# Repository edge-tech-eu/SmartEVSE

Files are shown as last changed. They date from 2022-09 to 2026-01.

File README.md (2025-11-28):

# SmartEVSE

ModBusRegisters.pdf lists the ModBus-RTU/RS485 registers. The SmartEVSE operates by default at 9600 BAUD (8 bits, no parity, 1 stop bit). Be aware that a state change (e.g. pressing the button on the board) is needed before communication is possible with the SmartEVSE with default address 1.

Note that important registers are protected by "magic" (first write the magic code, input register 0x0202) and settings are only persistent after writing them to EEPROM (input register 0x000a)

Installation.png is an quick overview on how to install the SmartEVSE

SmartEVSE mounts can be found in the '3d' folder

Are you looking for the guidelines on building your own charge point? Then continue [here](DHZ-laadpaal.md) (that document is in Dutch).

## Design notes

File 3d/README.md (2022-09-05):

This folder contains 3D designs of brackets to mount the SmartEVSE

The files with extension stl or 3mf can be 3D printed directly

The files with extension f3d are Autodesk Fusion 360 design files

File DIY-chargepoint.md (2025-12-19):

# DIY charging station
Voor Nederlands zie [hier](DHZ-laadpaal.md)

Look, we've done all the prep work for you!
We'll now help you put everything together step by step.

Follow the steps in the overview below:
1. [The basic configuration](installation/module-kl.png) – the “dumb charging station”, i.e. without load balancing
2. With power control (load balancing). Then choose one of the options below:
   - Use an ESP device or a Pi pico connected to a DSMR 4 or 5 smart meter and connect it to the charging station via an RS485 cable (Modbus)
   - Use a Raspberry Pi mini-computer with a USB cable connected to a DSMR 4 or 5 smart meter and an RS485 interface. Use the EVCC package to control the charging station
   - Use the Edgetech WiFi module:
     1. Do you have a DSMR5 smart meter? Then you can connect the EVSE-SC-02 module directly to the smart meter
     2. Do you not have a smart meter or do you have an older type? Then the current must be measured with current clamps (CT) and you will need type EVSE-SC-01.

> [!IMPORTANT]
> This document is written for experienced hobbyists. In other words, people who know how to safely connect devices to a 3-phase power cable.
> People who know what earth leakage circuit breakers are and understand the basic principles of connecting large power consumers via the meter box.
> We always recommend that changes to the meter box be carried out by a certified electrician.
# 1. The Basic configuration

With the basic configuration, you create a charging point without power control. This means that the charging point does not take other power users in the house into account. This can potentially cause problems if the power demand is too high. Therefore, ensure that you only charge when there is sufficient capacity available. This is typically the case from 10 p.m. to 4 a.m. Take into account the possible presence of heat pumps, home batteries and electric boilers. The basic configuration consists of the following components:

- charging module
- DC earth leakage module with connection cable
- charging cable
- housing and cable glands
- mounting brackets

You can easily assemble this housing yourself. You also have the option of using the mounting brackets if the standard mounting of the charging module is not suitable for your situation.

## Connecting the LED

You can connect a 5VDC or 12VDC LED to the charging module.

[Click here](installation/adding%20LED%20to%20charger.pdf) for the connection diagram.

## Assembly steps

- Below is an overview of all connections

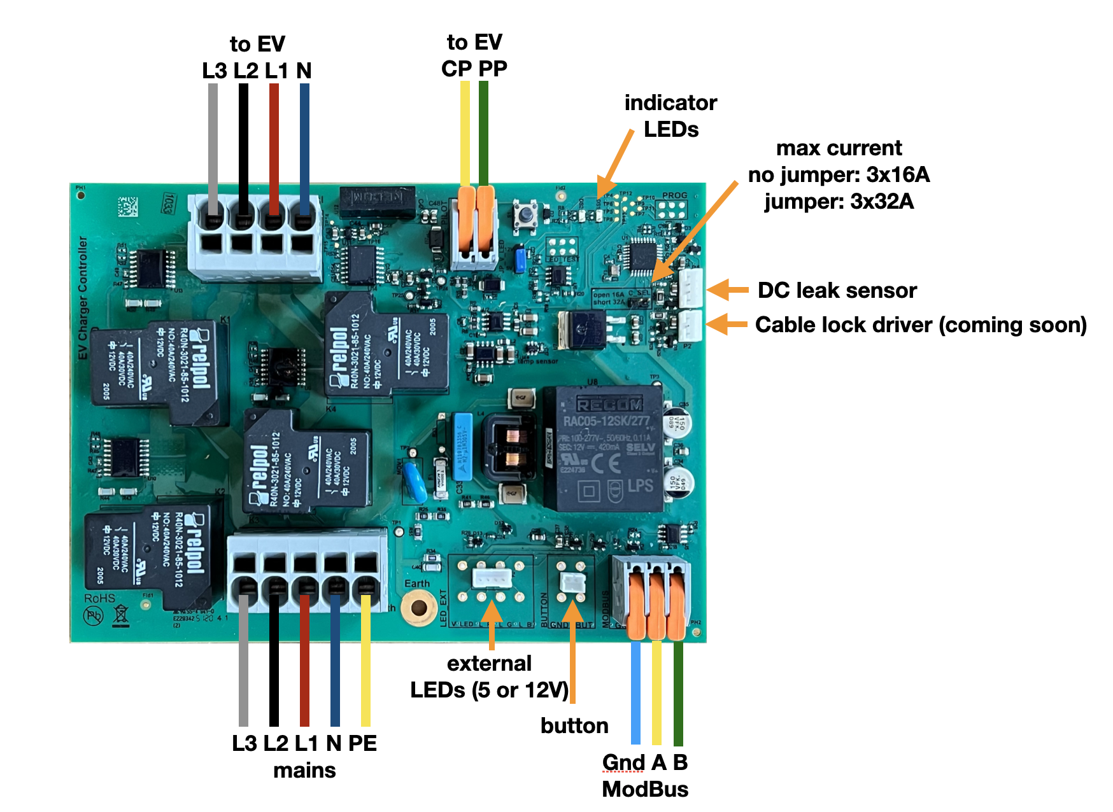
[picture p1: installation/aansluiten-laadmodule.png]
Connections


- Decide where to place the charging point. We recommend always installing a Modbus cable alongside the power cable. Make sure you use the **correct Modbus cable**. This cable, for example, is very suitable: https://www.elektroproducten.nl/product/stuurstroom-flex-liyy-3x05mm%C2%B2-per-meter/

- Choose a convenient location for mounting the glands for the incoming power cable and outgoing charging cable. Drill holes for the glands using a step drill. Also drill holes in the rear wall for secure mounting on a wall or pole. Make sure you seal the screw holes with, for example, a rubber ring or drip sealant.

- Choose the orientation of the charging module – screw it in place or glue the mounting brackets securely to the rear wall of the cabinet.

- Mount the charging module in the cabinet.

- Connect the DC earth leakage module to the charging module using the supplied wire.

- Connect the supplied earth wire (green-yellow) to the grey block with 5 inputs. Place this on input PE. Connect the other side to the supplied WAGO connector.

- Feed the charging cable through the cable gland. Then:

- Insert the wires into the correct outputs on the grey block with 4 outputs. Make sure you use the correct colours for the connection. Connect the earth wire (PE in the diagram / green-yellow) to the supplied separate WAGO connector. You can unlock the output by inserting a flat screwdriver into the rectangular hole – at that point, the wire can be inserted into the output.

  Insert the thin wire into the grey block with two orange levers, select the “PP” output, indicated in the diagram above by the yellow wire with “CP”. Make sure you click the lever all the way up and insert the wire deep enough into the output. Then click the lever back down and check that the wire is securely fastened.

- Now screw the housing onto the wall or pole and insert the power cable through the cable gland. Next:

- Insert the wires of the power cable into the correct inputs, paying close attention to the colours on the grey connector with 5 inputs.

  - Connect the earth wire (PE) to the WAGO connector.

  - Check that the wires in the grey connector do NOT touch each other. This can happen if wires with braided strands are used. Loose copper strands can remain just outside the input and cause a short circuit. So be careful!

- Does everything look good? Then you can activate the earth leakage circuit breaker in the fuse box. Check that the green LED on the charging module flashes every 3 seconds. See here for the location of the green LED:

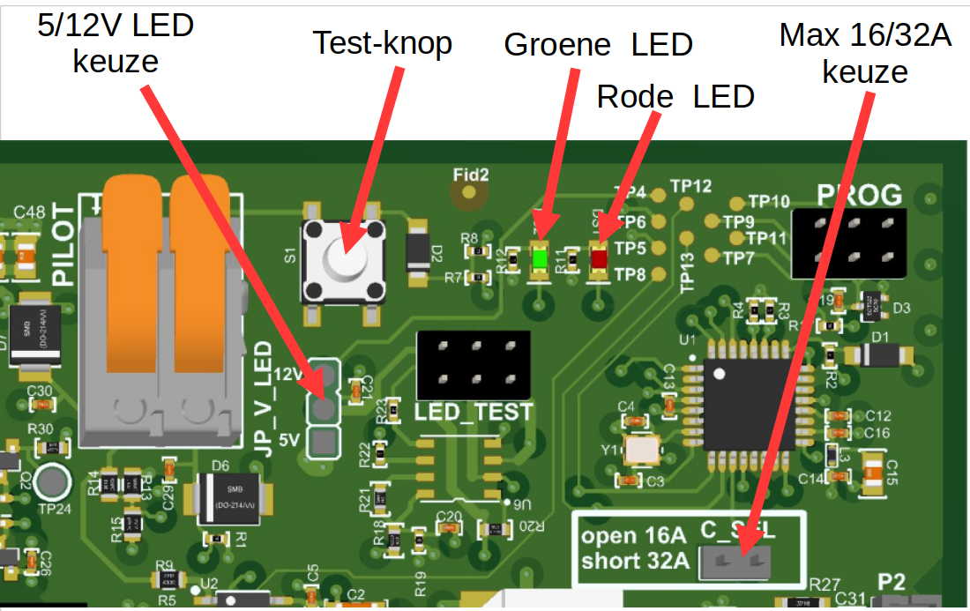
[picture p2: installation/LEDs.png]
LEDs


> [!IMPORTANT]
> If the red LED flashes, check that the earth is properly connected, both to the charging module and to the earth of the house.

## Test by charging a car

If you have followed the above steps and the LED on the charging module is flashing green,
you can check whether your car can be charged. Connect the charging cable to the car.
Is the car charging? Congratulations! If not, check the charging module and see if the red LED
is flashing occasionally. Depending on the flashing pattern, you can determine what the fault is:

| Condition | Red LED display |
| --- | --- |
| Start-up error (00000001) | Very long off, very short on |
| High temperature (10010000) | Short on, short off, short on, long off |
| Temperature too high, charging stopped (10011000) | Short on, short off, 2x short on, long off |
| No earth connected (10011100) | Short on, short off, 3x short on, briefly off |
| Relay remains switched on (10011110) | Short on, short off, 4x short on, short off |
| DC earth fault (10010110) | Short on, short off, short on, short off, 2x short on, short off |
| OK | Continuous off |

# 2. Load balancing

Load balancing is a good idea to protect your electricity connection from overload. If you use more energy than the main fuse can handle for too long, it will blow or trip. With old fuses, you will have to call your network operator to have the main fuse replaced. That costs money and takes a lot of time. In addition, it is also wise to charge at times when energy is cheap, or to relieve the electricity network. In short, you want to be able to control the time and charging, which is also known as load balancing. You can choose from one of the options below to enable load balancing. Of course, you can create the control yourself on a platform of your choice.

## A. Experienced hobbyist (e.g. Raspberry Pi Pico or ESPhome)

This option is suitable for people with programming experience on, for example, an Arduino or ESP platform. In addition, you must choose a programmable module that can be expanded with an RS485 (Modbus) interface. We have tested a Waveshare ESP32-S3 WiFi module with RS485 (https://www.waveshare.com/esp32-s3-relay-1ch.htm). Follow the Waveshare wiki (https://www.waveshare.com/wiki/ESP32-S3-Relay-1CH) for the correct connections and how to load code. A simple example of how to read the charging module can be found [here](Controllers).

All information about the charging module, such as connections and Modbus registers, can be found on [Github](/).

## B. Linux user: Raspberry Pi with EVCC

This option is suitable for people who have worked on a Linux system before and have some experience using the command line via a terminal.

The advantage of this choice is that you can, for example, choose a Raspberry Pi 3B to which a smart meter can also be connected with a special USB cable. Example configuration:

- Raspberry Pi 3B: e.g. at https://www.kiwi-electronics.com/nl/home/

- Smart meter P1 cable, see: https://www.sossolutions.nl/slimme-meter-kabel

- Without soldering, for example, a ‘Waveshare RS485 CAN HAT’. Waveshare provides clear documentation on a Wiki page on how to set this up for the Pi: https://www.waveshare.com/wiki/RS485_CAN_HAT#RS485_Usage This module is available from Tinytronics, https://www.tinytronics.nl/nl/communicatie-en-signalen/serieel/rs-485/waveshare-rs485-can-hat-voor-raspberry-pi

In the overview below, we assume you are using a Raspberry Pi model 3B.

Follow these steps:
- Use the Raspbian Imager ( https://www.raspberrypi.com/software/ ) to write the SD card for the Raspberry. Make sure you choose a host name that you can find again, e.g. load balancer. If you have a Pi without Ethernet, also enter the WiFi details so that you can always access the Pi remotely with ssh.
  - Follow the steps to connect the Pi to your network.
  - Open a terminal or log in with ssh on the Pi
  - Follow the steps at https://docs.evcc.io/en/docs/installation
  - Select the Edgetech Smart EVSE in the configuration
  - Select the correct adapter for the Modbus adapter, Modbus address 2, baud rate 9600, 8N1. This is an example from the evcc.yaml file for the Waveshare adapter:

```configuration
chargers:
- type: template
  template: smartevse
  id: 2
  device: /dev/ttyS0
  baud rate: 9600
  comset: 8N1
  modbus: rs485serial
  name: charging point 1

```

- Do you also have the smart meter P1 cable? Then you also need to install the ser2net software package on the Pi. Follow the ser2net manual to make the serial port accessible via a network socket.

Below is an example of the definition of the grid meter in the evcc.yaml file and below that an example configuration of ser2net.conf:
```configuration
####################
#blok voor EVCC
meters:
- type: template
  template: dsmr
  usage: grid
  host: 127.0.0.1  # host: ser2net
  port: 2000
  name: grid
###################
```

```
###################
#blok voor ser2net.yaml
%YAML 1.1
---
# This is a ser2net configuration file, tailored to be rather simple.
define: &banner \r\nser2net port \p device \d [\B] (Debian GNU/Linux)\r\n\r\n

connection: &conDSMR
    accepter: tcp,2000
    enable: on
    options:
      max-connections: 3
      kickolduser: true
      telnet-brk-on-sync: true
    connector: serialdev,
              /dev/ttyUSB0,
              115200n81,local
###################
```

- Then follow the steps at https://docs.evcc.io/en/docs/installation

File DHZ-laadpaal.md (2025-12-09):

# DHZ laadpaal
Kijk, wij hebben alle voorbereidingen voor je gedaan!
We zullen je nu stap voor stap helpen om alles in elkaar te zetten.

Volg de stappen in onderstaande overzicht:
1. [De basis-configuratie](installation/module-kl.png) – de “domme laadpaal”, dus zonder stroomsturing (load-balancing)
2. Met stroomsturing (load-balancing). Kies dan uit één van onderstaande opties:
    - Gebruik een ESP-device of een Pi-pico gekoppeld aan de een DSMR 4 of 5  slimme meter en verbind deze via een RS485-kabel (Modbus) aan het laadstation
    - Gebruik een Raspberry Pi mini-computer met USB-kabel aan een DSMR 4 of 5 slimme meter en een RS485-interface. Gebruik het pakket EVCC om het laadstation aan te sturen
    - Gebruik de Edgetech WiFi-module:
      1. Heeft u een DSMR5 slimme meter? Dan kunt de EVSE-SC-02 module rechtstreeks aan de slimme meter koppelen
      2. Heeft u geen slimme meter of een ouder type? Dan moet de stroom met stroomklemmen (CT) gemeten worden en heeft u type EVSE-SC-01 nodig.

> [!IMPORTANT]
> Dit document is geschreven voor ervaren hobbyïsten. Dus mensen die op een veilige manier apparaten op een 3-fase voedingskabel kunnen aansluiten.
> Die weten wat aardlekautomaten zijn en de basis-principes kennen voor het aansluiten van grote stroomgebruikers via de meterkast.
> Wij raden altijd aan om wijzigingen in de meterkast door een erkende elektricien uit te laten voeren.

# 1. De Basis-configuratie
Met de basis-configuratie maak je een laadpunt zonder stroomsturing. Dat betekent dat het laadpunt geen rekening houdt met andere stroomgebruikers in het huis. Dit kan mogelijk voor problemen zorgen bij te grote stroomvraag. Zorg dat je dus alleen laadt op die momenten dat er voldoende capaciteit beschikbaar is. Dat is typisch het geval vanaf ‘s avonds 22 uur tot 4 uur in de ochtend. Houdt dus rekening met moglijk aanwezigheid van warmtepompen, thuis-accu’s en elektrische boilers. De basis-configuratie bestaat uit deze onderdelen:
- laad-module
- DC-aardlek-module met aansluitkabel
- laadkabel
- behuizing en wartels
- montage-beugels

Je kunt deze behuizing zelf eenvoudig in elkaar zetten. Je hebt zelf nog de keuze om de montage-beugels te gebruiken als de standaard-montage van de laad-module niet geschikt is voor jouw situatie.

## LED aansluiten
Op de laad-module kun je een 5VDc of 12VDC LED aansluiten.
[Kijk hier](installation/adding%20LED%20to%20charger.pdf) voor het aansluitschema.

## Stappen voor de assemblage
- Hieronder vind je het overzicht van alle aansluitingen
Aansluitiingen
- Bepaal waar het laadpunt wordt geplaatst. We raden aan om altijd ook een Modbus-kabel naast de voedingskabel aan te leggen. Let er op dat u de **juiste Modbus-kabel gebruik**t. Deze kabel is bijvoorbeeld heel geschikt: https://www.elektroproducten.nl/product/stuurstroom-flex-liyy-3x05mm%C2%B2-per-meter/
- Kies de handige plaats voor montage van de wartels voor de ingaande voedingskabel en uitgaande laadkabel. Boor gaten voor de wartels met een stappenboor. Boor ook gaten in de achterwand voor stevige montage op een muur of paal. Let er op dat je de schroefgaten waterdicht maakt met b.v. een rubberring of druppel kit.
- Kies de oriëntatie van de laad-module – schroef deze vast of lijm de montagebeugels goed aan de achterwand van de kast.
- Monteer de laad-module in de kast.
- Verbind de DC-aardlek-module aan de laad-module met de meegeleverde draad
- Verbind de meegeleverde draad aardedraad (groen-geel) met het grijze blok met 5 ingangen. Plaats deze op ingang PE. Verbind de andere zijde met de meegeleverde WAGO-connector.
- Voer de laadkabel door de wartel heen. Vervolgens:
  - steek de aders in de juiste uitgangen op het grijze blok met 4 uitgangen. Let op de juiste kleuren voor het verbinden. Sluit de aarde-ader (PE in het plaatje / groen-geel) aan op de meegeleverde losse WAGO-connector. Je kunt de uitgang ontgrendelen door een platte schroevendraaier in het rechthoekige gat te steken – op dat moment kan de ader in de uitgang worden gestoken.
  - Steek de dunne ader in het grijze blokje met twee oranje heveltje, kies daar de uitgang “PP”, in het plaatje hierboven aangeduid met gele draad met “CP”. Zorg dat je het heveltje helemaal omhoog klikt en de ader diep genoeg in de uitgang steekt. Klik dan het heveltje weer omlaag en controleer dat de ader goed vast zit.
- Schroef de behuizing nu vast op de muur of paal en steek de voedingskabel door de wartel. Vervolgens:
  - Steek de aders van de voedingskabel in de juiste ingangen, let goed op de kleuren op de grijze connector met 5 ingangen.
  - Verbind de aarde-ader (PE) met de WAGO-connector
  - Controleer dat de aders in de grijze connector onderling GEEN contact maken. Dat kan het geval zijn indien er aders met gevlochten draad gebruikt worden. Dan kunnen losse koper draadjes net buiten de ingang blijven zitten en kortsluiting veroorzaken. Let dus goed op!
- Ziet alles er goed uit? Dan kun je de aardlekautomaat in groepenkast activeren. Controleer dat het groene LEDje op de laad-module elke 3 seconden knippert. Zie hier voor de plaats van het groene LEDje:
LEDs
> [!IMPORTANT]
> indien het rode LEDje knippert controleer dan of de aarde goed is aangesloten, zowel op de laad-module als ook verbonden met de aarde van het huis.

## Test met het opladen van een auto
Als u bovenstaande stappen heeft gevolgd en het LEDje op de laad-module groen knippert dan kunt u gaan controleren of uw auto opgeladen kan worden. Sluit de laadkabel op de auto aan. Gaat de auto laden? Gefeliciteerd! Is dat niet het geval kijk dan op de laad-module en controleer of de rode LED af & toe knippert. Afhankelijk van de volgorde van knipperen kunt u bepalen wat de fout is:

| Conditie | Weergave rode LED |
|---|---|
| Fout bij opstarten (00000001) | Heel lang uit, erg kort aan |
| Temperatuur hoog (10010000) | Kort aan, kort uit, kort aan, lang uit |
| Temperatuur te hoog, laden gestopt (10011000) | Kort aan, kort uit, 2x kort aan, lang uit |
| Geen aarde aangesloten (10011100) | Kort aan, kort uit, 3x kort aan, even uit |
| Relais blijft ingeschakeld (10011110) | Kort aan, kort uit, 4x kort aan, kort uit |
| DC-aardlek (10010110) | Kort aan, kort uit, kort aan, kort uit, 2x kort aan, kort uit |
| Ok | Continue uit |

# 2. Load-balancing
Load-balancing is een goed idee om je elektriciteitsaansuiting te beschermen tegen overbelasting. Als je namelijk te lang meer energie gebruikt dan de hoofdzekering aan kan zal deze doorbranden of afslaan. Bij oude zekeringen zul je je netbeheerder moeten bellen om de hoofdzekering te laten vervangen. Dat kost geld en veel tijd. Daarnaast is het ook verstandig om te laden op die momenten dat energie goedkoop is, danwel om het elektriciteitsnetwerk te ontlasten. Kortom, je wilt de tijd en het laden kunnen sturen en dat wordt ook wel load-balancing genoemd. Je kunt kiezen uit één van onderstaande mogelijkheden om load-balancing mogelijk te maken. Natuurlijk kun je de aansturing zelf maken op een platform van jouw keuze.

## A. Ervaren hobbyïst (bv Raspberry Pi Pico of ESPhome)
Deze optie is geschikt voor mensen met programmeerervaring op bijvoorbeld een Arduino of ESP-platform. Daarnaast moet je een programmeerbare module kiezen die kan worden uitgebreid met een RS485 (Modbus) interface. Wij hebben een Waveshare ESP32-S3 WiFi-module met RS485 getest (https://www.waveshare.com/esp32-s3-relay-1ch.htm). Volg de wiki van Waveshare (https://www.waveshare.com/wiki/ESP32-S3-Relay-1CH) voor de juiste aansluitingen en wijze van het laden van code. Een eenvoudig voorbeeld om de laad-module uit te lezen staat [hier](Controllers).
Alle informatie over de laad-module zoals aansluitingen en Modbus-registers staan op [Github](/)

## B. Linux-gebruiker: Raspberry Pi met EVCC
Deze optie is geschikt voor mensen die wel eens op een Linux-systeem hebben gewerkt en enige ervaring hebben in het gebruik met de command line via een terminal.
Het voordeel van deze keuze is dat je bijvoorbeeld een Raspberry Pi 3B kunt kiezen waarop ook een slimme meter kan worden aangesloten met een speciale USB-kabel. Voorbeeld configuratie:
- Raspberry Pi 3B: b.v. bij https://www.kiwi-electronics.com/nl/home/
- Slimme meter P1-kabel zie: https://www.sossolutions.nl/slimme-meter-kabel
- Zonder solderen bijvoorbeeld een “Waveshare RS485 CAN HAT”. Waveshare documenteert netjes met een Wiki-pagina hoe je deze voor de Pi moet instellen: https://www.waveshare.com/wiki/RS485_CAN_HAT#RS485_Usage Deze module is te koop bij Tinytronics, https://www.tinytronics.nl/nl/communicatie-en-signalen/serieel/rs-485/waveshare-rs485-can-hat-voor-raspberry-pi

In onderstaande overzicht gaan we uit van een Raspberry Pi model 3B.

Volg de onderstaande stappen
- Gebruik de Raspbian Imager ( https://www.raspberrypi.com/software/ ) om het SD-kaartje voor de Rapsberry te schrijven. Let erop dat je een hostnaam kiest die je terug kunt vinden, bv loadbalancer. Heb je een Pi zonder Ethernet vul dan ook de WiFi-gegevens in zodat je altijd op afstand bij de Pi met ssh.
- Volg de stappen om de Pi met je netwerk verbonden te krijgen.
- Open een terminal of login met ssh op de Pi
- Volg dan de stappen op https://docs.evcc.io/en/docs/installation
- Kies in de configuratie voor de Edgetech Smart EVSE
- Kies de juiste adapter voor de Modbus-adaper, Modbus-adres 2, baudrate 9600, 8N1. Dit is een voorbeeld-stuk uit de evcc.yaml file voor de Waveshare adapter:

```configuration
chargers:
- type: template
  template: smartevse
  id: 2
  device: /dev/ttyS0
  baudrate: 9600
  comset: 8N1
  modbus: rs485serial
  name: laadpunt1
```

- Heb je ook de slimme meter P1-kabel? Dan moet je op de Pi ook het software-pakket ser2net installeren. Volg de handleiding van ser2net om de seriële poort via een netwerk-socket bereikbaar te maken.
Hieronder een voorbeeld van de definitie van de grid-meter in de evcc.yaml file en daaronder een voorbeeld configurtie van ser2net.conf:
```configuration
####################
#blok voor EVCC
meters:
- type: template
  template: dsmr
  usage: grid
  host: 127.0.0.1  # host: ser2net
  port: 2000
  name: grid
###################
```
```
###################
#blok voor ser2net.yaml
%YAML 1.1
---
# This is a ser2net configuration file, tailored to be rather simple.

define: &banner \r\nser2net port \p device \d [\B] (Debian GNU/Linux)\r\n\r\n

connection: &conDSMR
    accepter: tcp,2000
    enable: on
    options:
      max-connections: 3
      kickolduser: true
      telnet-brk-on-sync: true
    connector: serialdev,
              /dev/ttyUSB0,
              115200n81,local
###################
```

- volg de stappen onder https://docs.evcc.io/en/docs/features/loadmanagement om load-balancing toe te voegen

# C. Edgetech WiFi-module
## 1. EVSE-SC-01 met CT-klemmen
*Deze optie is voor mensen die geen slimme meter hebben van het type DSMR5.*

Wilt u zelf toch niet met de aansturing via Modbus aan de gang maar wel zelf alles aanleggen, dan is deze optie geschikt voor u.
[Hier](installation/module-site-kl.png) ziet u de configuratie. Voor deze configuratie moet je dus een extra module in de groepenkast plaatsen.
Verder moet u de CT-klemmen om voedingsaders van de hoofdaansluiting plaatsen.

## 2. EVSE-SC-02 met RJ12-kabel
*Deze optie is voor mensen met een slimme meter van het type DSMR5.*

Met de EVSE-SC-02 kunt u heel snel en eenvoudig load-balancing toevoegen. Voor de rest geldt ook hier dat de juiste Modbus-kabel gebruikt
moet worden en de handleiding gevolgd moet worden. Omdat er geen stroomklemmen geplaatst hoeven worden en deze module buiten de meterkast
wordt geplaatst is deze optie eenvoudiger voor de installatie. Ook scheelt het ruimte in de groepenkast.
[Hier](installation/module_site-sm-kl.png) ziet u de configuratie.

Voor deze twee opties (EVSE-SC-01 en EVSE-SC-02) zijn de volgende aandachtspunten belangrijk:
- Let er op dat u de juiste Modbus-kabel gebruikt. Deze kabel is bijvoorbeeld heel geschikt: https://www.elektroproducten.nl/product/stuurstroom-flex-liyy-3x05mm%C2%B2-per-meter/
- U kunt de handleiding voor de installatie vinden op:  https://github.com/edge-tech-eu/SmartEVSE/tree/main
- Deze modules maken gebruik van een cloud-server. U kunt deze gratis de eerste 60 dagen gratis gebruiken. Zie voor alle details wat u met het abonnement kunt https://mycharger.edgetech.nl/. Verder kun je ook een API gebruiken om zelf het proces van starten en stoppen van laden aan te sturen, zie informatie hierover op https://mycharger.edgetech.eu/ waarin aansturing vanuit HomeAssistant wordt uitgelegd.  Zonder abonnement werkt load-balancing gewoon verder, maar kunt u niet meer aansturen.

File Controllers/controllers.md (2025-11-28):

wifi -> rs485

https://www.waveshare.com/esp32-s3-relay-1ch.htm

smartmeter -> rs485

https://www.waveshare.com/rp2350-lcd-4.htm

wifi or smartmeter -> rs 485

https://lilygo.cc/products/t-panel-s3

ethernet or smartmeter -> rs485

https://wiznet.io/products/evaluation-boards/w55rp20-evb-pico

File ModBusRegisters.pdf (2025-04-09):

### Table 1

document: | ModBusRegisters for Edge Technologies' EV Charger Controller (SmartEVSE)
version: | 2.10.17
date: | 20250409
contact: | support@edgetech.eu
communication: | ModBus over RS485 with default parameters: address 0x01* @ 9600 8N1
firmware: | 2.10.17

*: while address is 0x01 the device will only respond to modbus when a state change has occurred. (e.g. by pressing the button on the board).

### Input Registers (Read Only, fc = 4)

Address | Name | Size | Description
0000 | SerialNumber | 5 | Device's serial number
0005 | FirmwareVersion | 1 | Firmware version of the application
0006 | MsSinceBoot | 4 | Milliseconds since boot
000A | SaveEEPROM* | 1 | Persist settings (in EEPROM)
000B | FactoryDefaults* | 1 | Reset settings to factory defaults
000C | Reset* | 1 | Restart application
000D | EnterBootloader* | 1 | Enter bootloader mode
000E | ChallanceResponse | 1 | Used to verify code
000F | EnableTestMode | 1 | Not used
0010 | ExternalLock | 1 | Active external cable lock (return: 0 = unlocked, 1 = locked, 0xFFFF = lock port is used as CP disconnect)
0011 | I2c errors | 1 | Read and reset number of internal I2C errors
0012 | Quiet reset | 1 | Quiet reset
0013 | Conditional answer | 1 | Conditional response
0014 | Conditional address | 1 | Conditional response
0015 | Lock lock | 1 | Lock the lock (return: 1 = locked, 0xFFFF = lock port is used as CP disconnect)
0016 | Unlock lock | 1 | Unlock the lock (return: 0 = unlocked, 0xFFFF = lock port is used as CP disconnect)
0017 | Disconnect CP | 1 | CP will be momentarily disconnected if set to do so (return: 1: disconnected, 0xFFFF = not configured for CP disconnect)

*: protected by magic (default: 0x1234)

### Input Registers (Read Only, fc = 4)

Address | Name | Registers | Description
0100 | MinPilot | 1 | Minimum value measured of pilot signal
0101 | MaxPilot | 1 | Maximum value measured of pilot signal
0102 L | MaxCableCurrent | 1/2 | Current rating of attached cable
0102 H | MaxCurrent | 1/2 | Advertised current
0103 L | State | 1/2 | IEC61851 state:
0103 H | Error | 1/2 | Error code (see error code tabel)
0104 | Temperature | 1 | Temperature of board
0105 | CurrentL1 | 1 | Current draw measured on L1
0106 | CurrentL2 | 1 | Current draw measured on L2
0107 | CurrentL3 | 1 | Current draw measured on L3
0108 | EnergySession | 1 | Energy delivered (in 1/256 KWh) during current charging session
0109 | VoltageL1 | 1 | Voltage on L1 output
010A | VoltageL2 | 1 | Voltage on L2 output
010B | VoltageL3 | 1 | Voltage on L3 output
010C | Options | 1 | bits: 7: x, 6: x, 5: x, 4: x, 3: x, 2: x, 1: 32A/16A, 0: DCL
010D | Energy | 2 | Total energy delivered (in 1/256 KWh) by board (010d + 010e<<16)
010F | EnergySessionL1 | 1 | Energy delivered (in 1/256 KWh) during current charging session on L1
0110 | EnergySessionL2 | 1 | Energy delivered (in 1/256 KWh) during current charging session on L2
0111 | EnergySessionL3 | 1 | Energy delivered (in 1/256 KWh) during current charging session on L3
0112 | Earth quality | 1 | Earth quality (experimental feature)
0113 | UBRR | 1 | Baud rate UBRR

### Input Registers (Read/Write, fc = 3/5/6)

Address | Name | Size | Description
0200 L | ModbusAddress | 1/2 | Modbus address*
0200 H | Discovery | 1/2 | Not used
0201 L | RemoteMaxCurrent | 1/2 | Limiting advertised current to this value
0201 H | RemoteMaxCurrentNextSecond | 1/2 | Limiting advertised current to this value for the next second
0202 | MagicResetCode | 1 | Used to change magic code
0203 | Challange | 1 | Used to verify code
0204 | Settings | 1 | bits: 7: x, 6: x, 5: EV40_CP_DISCONNECT, 4: AUTO_CP_DISCONNECT,3: MISUSE_LOCK_PORT_AS_CP_DISCONNECT, 2: DCL_MUST_BE_PRESENT, 1: LOCK_STATE, 0: PHASES
0205 | Led | 1 | value: 0: GRB_ONBOARD, 1: NEO_STRIP_36
0206 | Condition | 1 | Conditional response
0207 | UBRR | 1 | Baud rate UBRR
0208 | CPDisconnectTime | 1 | Time (in ms) to disconnect CP (if set to do so)
0209 | TimeBeforeCPDisconnect | 1 | Time (in ms) to wait after advertising current to check STATE_C and if not disconnect CP
020A L | CPType | 1/2 | CP type: 0 = normal, 1 = use A1 and B1
020A H | CPDisconnectType | 1/2 | CP disconnect type: 0 = EV40, 1 = extended EV40
| | | *: while address is 0x01: the device will only respond to modbus requests after a state change has occurred. (e.g. by pressing the button on the board).

### Bootloader registers (ModBus address 0xF0)

Address [hex] | Function Code [hex] | Registers | Name | Description
500 | 4 | - | BootloaderVersion | Bootloader version or 0 when address at application modbus address
address | 10 | 64 | FlashPage | low address byte indicates flash page, high address indicates "this is the last page"

### Error codes

Error code | Description

0 No error
1 Temperature too high
2 Stuck relay
4 Ground fault
8 Max CP too low
16 Min CP too high
32 DCL triggered
64 I2C initialization failed 128 I2C communication error

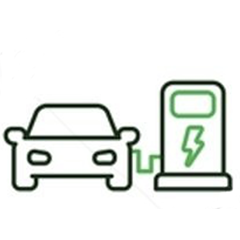
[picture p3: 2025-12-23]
Controllers/Control_Charger/LilyGo_T-Panel-S3_LCD/images/charging.png

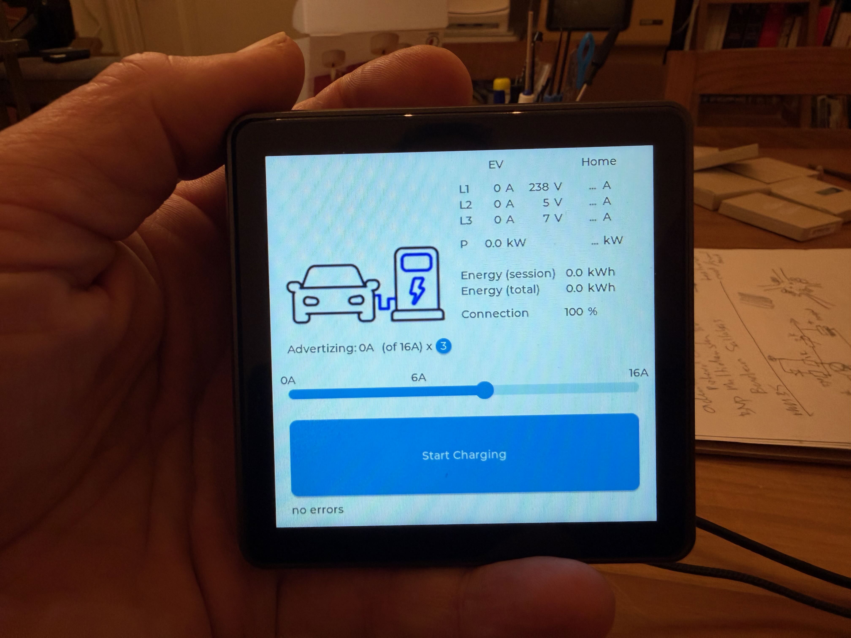
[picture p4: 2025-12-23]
Controllers/images/lilygo_tpanel_example_1.jpeg

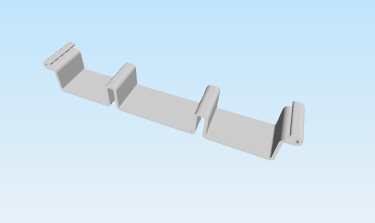
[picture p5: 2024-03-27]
3d/image_2024_03_26T17_05_00_189Z.png

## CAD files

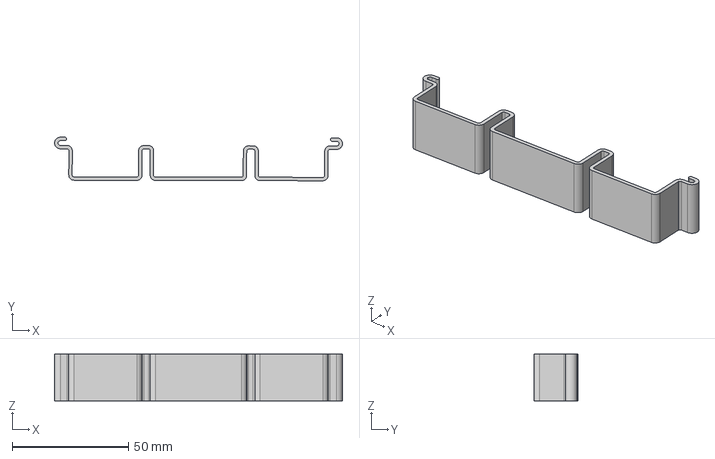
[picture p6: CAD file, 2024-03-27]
3d/bracket.step
123.8 x 18.7 x 20.0 mm

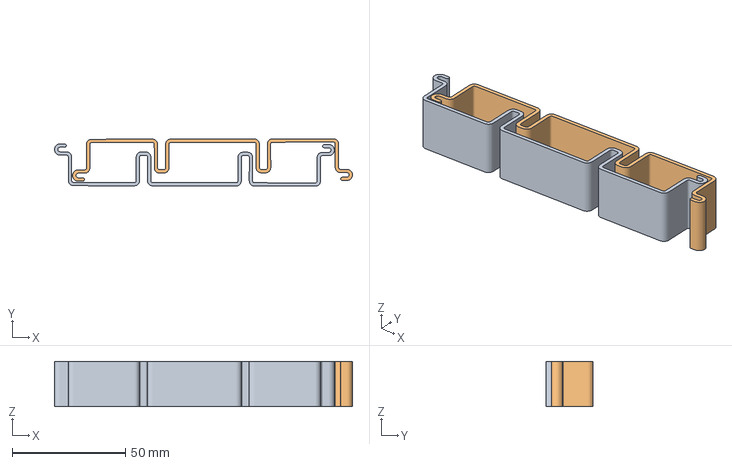
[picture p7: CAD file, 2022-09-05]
3d/double bracket v3.3mf
131.8 x 21.0 x 20.0 mm

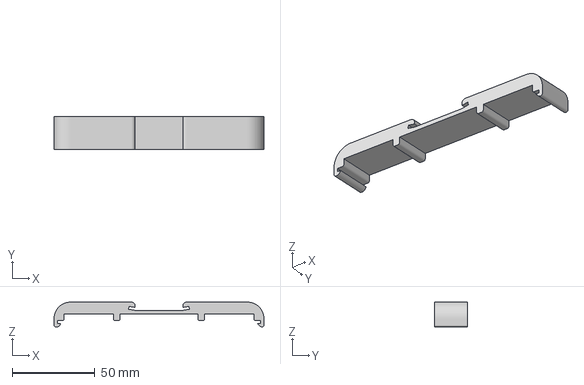
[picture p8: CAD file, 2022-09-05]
3d/socket-din-rail-mount v1.3mf
127.0 x 20.0 x 15.0 mm

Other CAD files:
3d/bracket c-thickness parameterized v3.3mf
3d/bracket c-thickness parameterized v3.f3d
3d/bracket c-thickness parameterized v3.stl
3d/double bracket v3.f3d
3d/double bracket v3.stl
3d/socket-din-rail-mount v1.f3d
3d/socket-din-rail-mount v1.stl

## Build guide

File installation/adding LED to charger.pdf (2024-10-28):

VLED

B

LED EXT

R G

4-pin JST-PH

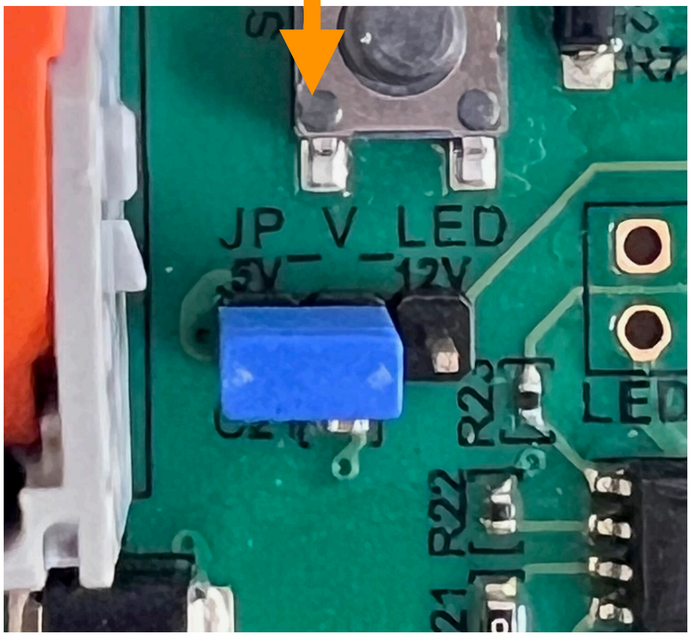
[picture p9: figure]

Voltage of LED (on VLED) can be 5V or 12V and is selected by jumper on JP_V_LED (see also next page)

VLED

+5V +12V

JP_V_LED

0.1" jumper

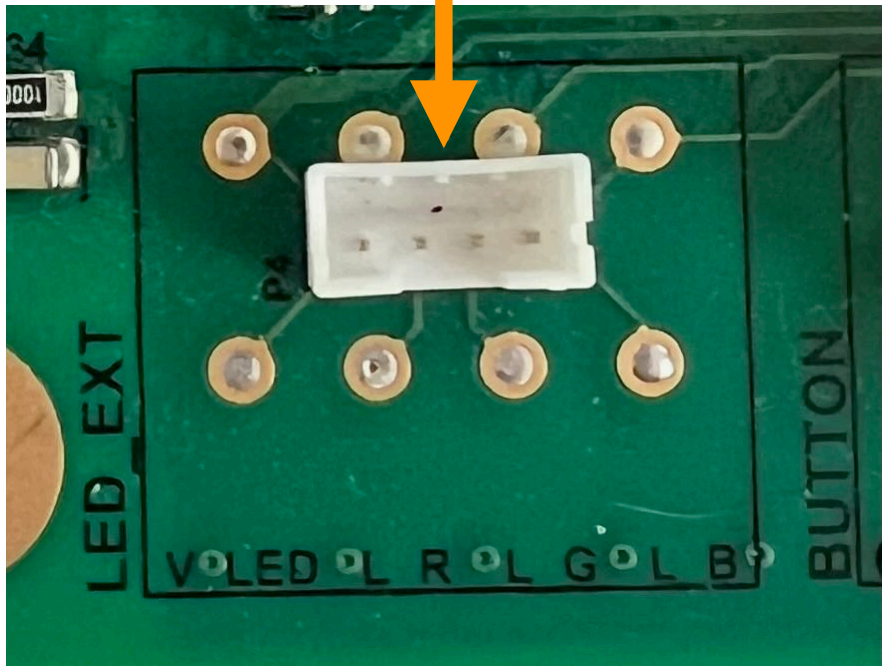
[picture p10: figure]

Use 4-pin JST-PH connector to connect an external common cathode RGB LED (or 3 separate LEDs)

LED TEST
connector

R
G
B

VLED
Dout
GND

1

3

5

2

4

6

2x3 0.1" header

LED TEST connector (solder) has the same connections as LED EXT.

LED TEST can also output digital output for WS2811 type
addressable LEDs. External power is required if using more than one addressable LED

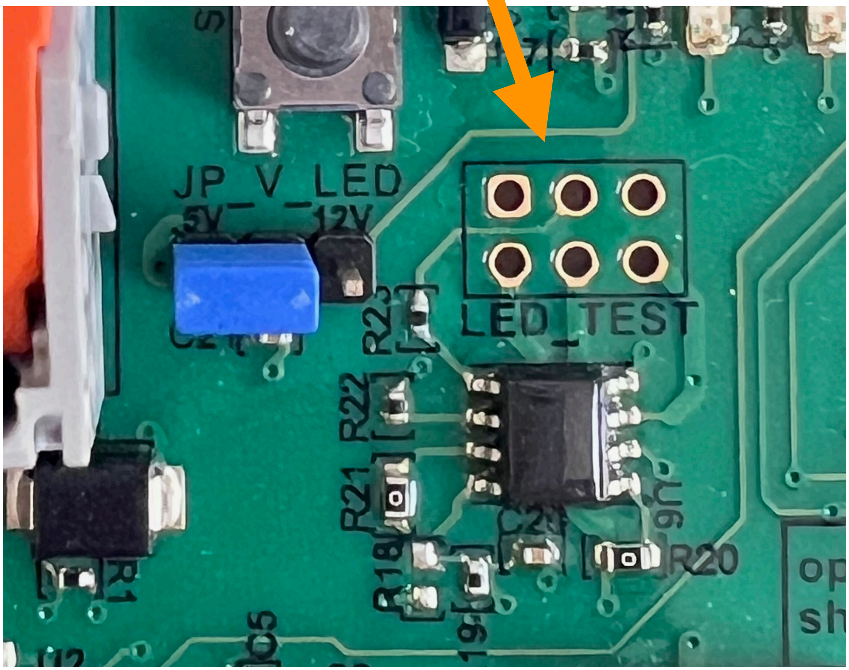
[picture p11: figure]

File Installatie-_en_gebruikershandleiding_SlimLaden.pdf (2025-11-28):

# Installatie- en gebruikershandleiding SlimLaden!

Instructievideo: bovenstaande QR-code is de Internet-link https://vimeo.com/727822542 . Lees altijd eerst deze handleiding door. De video is een installatie met toelichting door een installateur die al eens eerder een SlimLaden!-oplossing heeft gemonteerd.

Dit document bevat technische documentatie van de Slimladen!-oplossing bestaande uit de Wifi-module EVSE-SC-01 (of EVSE-CS-02), het laadpunt EVSE-C-3x32A en optionele DC-aardlek-module EVSE X-DCD. Het document bevat tevens installatie-instructies voor het laadpunt en WiFi-module. Vanaf hoofdstuk 7 leert u over het gebruik van de mobiele app.

Het SlimLaden!-laadstation kan naar eigen voorkeur buiten op een eigen paal, aan de wand of in huis geplaatst worden. Houd wel rekening met voldoende lengte voor de laadkabel. Indien u de mogelijkheid heeft om het laadstation in een garage of kelder op te hangen kan dat gunstig zijn voor onnodig opwarmen. In die situatie kunt u met een vaste laadkabel buiten de garage of kelder uw laadkabel aan een paal of de muur ophangen en is het laadstation verder uit het zicht.

De installatie-instructies leiden u door de stappen heen die noodzakelijk zijn om veilig en optimaal het SlimLaden!-laadstation te gebruiken. U neemt dan de volgende stappen:

1 de groepenkast aanpassen voor de WiFi-module en aardlekautomaat

2 het verbinden van de groepenkast met het SlimLaden!-laadstation (stroom en data)

3 de werking controleren van het laadstation

4 installatie en in gebruik nemen van de mobiele applicatie (“mobiele app”)

De SlimLaden!-oplossing is een product van Edge FS B.V.

Edge FS BV | Web: https://www.edg etech.eu Email: support@edgetech.eu Tel. 085 401 1061

### 1. Algemene kenmerken

WiFi-module
Fabrikant | Edge FS BV
Referentie | EVSE-SC-01 en EVSE-SC-02
Nominale voltage / frequentie/vermogen | 90 - 300 VAC / 50 Hz
Maximale stroom / vermogen (AC-zijde) | 300 mA / 3 Watt
Beschermingsgraad van de behuizing | IP00
Klasse | Class I / Klasse 1 (IEC 61140)
WLAN | IEEE 802 11b/g/n
CE-verklaring (EU) | https://mycharger.edgetech.nl//CE_ChargerController.pdf

Laadpunt
Fabrikant | Edge FS BV
Referentie | EVSE-C-3x32A
Nominale voltage / frequentie / vermogen | 90 - 300 V / 50 Hz / 3 Watt
Maximale stroom / vermogen (AC-zijde | 100 mA
Beschermingsgraad van de behuizing | IP00
Klasse | Class I / Klasse 1 (IEC 61140)
CE-verklaring (EU) | https://mycharger.edgetech.nl//CE_SiteController.pdf

### 2. Veiligheid en aanbevelingen

Installatie- en onderhoudswerkzaamheden dienen uitsluitend te worden verricht door erkende / gecertificeerde installateurs die kennis hebben genomen van deze handleiding en werken volgens de relevante richtlijnen waaronder IEC-60364 en NEN3140;

Verdere aanbevelingen:
1 De elektrische installatie dient tijdens alle installatie- en onderhoudswerkzaamheden spanningsloos te zijn

2 Werkzaamheden mogen niet worden uitgevoerd bij regen of bij een luchtvochtigheid
| van boven de 95%
3 Gebruik de juiste aderdikte (b.v. https://www.elektramat.nl/kennisbank/aderdikte/ )
4 Het laden van de EV kan met een vaste laadkabel of een Mennekes-
| wandcontactdoos (WCD) waarbij de diameter van de aders in de laadkabel voldoende dik moeten zijn voor het veilig geleiden van de laadstroom conform NEN 1010

5 Zeker elke individuele laadpaal af voor de gewenste maximale stroom. Houdt er
| daarbij rekening mee dat de collectieve stroomopname niet voorbij de aansluitwaarde van de hoofdaansluiting komt.

6 In complexere installaties kan er gekozen worden worden om alle laadpalen ook nog
| achter 1 hoofdzekering te plaatsen, zodat mogelijke overbelasting van alle laadpalen bij elkaar opgeteld correct afgezekerd is ten opzicht van de maximale stroom van de aanvoerkabel en de maximale stroom van de netwerk-aansluiting.

7 De WiFi-module is ontworpen om in de groepenkast te plaatsen. Zorg er voor dat
| deze module altijd in een beschermde omgeving binnenshuis wordt geplaatst en de contacten niet eenvoudig kunnen worden aangeraakt. De WiFi-module moet achter een zekering worden geplaatst.

Modbus
De communicatie tussen WiFi-module en laadpunt loopt via een Modbus-kabel. Voor afstanden van meer dan 5 meter is het noodzakelijk om de juiste signaalkabel te gebruiken. Wij raden het gebruik van ethernet-kabel af (zoals Cat5 of Cat6), omdat deze voor hele andere overdracht van elektrische signalen is gemaakt. We raden een signaalkabel zoals https://www.elektroproducten.nl/product/stuurstroom-flex-liyy-3x05mm%c2%b2-per-meter/ aan.

### 3 aders met een dikte van minimaal 0,5 mm2 is noodzakelijk voor de juiste

signaaloverdracht. Bovenstaande kabel heeft gevlochten aders waardoor de kans op een breuk verkleind wordt.

### 3. Overzicht onderdelen SlimLaden!

SlimLaden! bestaat uit twee onderdelen: 1) een SlimLaden!-laadpaal en 2) een SlimLaden!-meterkast-module voor in de groepenkast:

1. De SlimLaden!-laapdaal (EVSE-C-3x32A) is een elektrisch apparaat dat elektrische voertuigen (EV) kan opladen volgen de norm NEN-EN-IEC 61851-22 waarbij SAE J1772 als belangrijke referentie is gebruikt. De EVSE Controller dient uitsluitend gebruikt te worden voor het laden van elektrische auto’s (EVs) in Mode 3 volgens Standaard ISO 17409 en Standaard IEC 61851. Verder zorgt de EVSE-X-DCD module voor de controle op DC-aardlekstromen van maximaal 6mA. Deze module moet in de laadpaal op de laad-controller worden aangesloten.
2. Er zijn twee type SlimLaden!-meterkast-modules:
1. Module EVSE-SC-01: dit is een electrisch apparaat dat laadpunten van het type EVSE-C-3x32A via RS485/Modbus kan aansturen. Dit apparaat wordt in de groepenkast geplaatst en met een computer-netwerk verbonden via WLAN (WiFi). Deze module wordt gevoed met 220 VAC verbonden met een zekering in de groepenkast.
2. Module EVSE-SC-02: dit is een electrisch apparaat dat laadpunten van het type EVSE-C-3x32A via RS485/Modbus kan aansturen. Dit apparaat wordt buiten de groepenkast geplaatst en verbonden met de slimme meter van type DSMR 5.0 of hoger. De verbinding met een computer-netwerk is op basis van WLAN (WiFi) of Ethernet (RJ45 LAN-kabel). Deze module wordt gevoed vanuit de slimme meter.

De functies en mogelijkheden van beide onderdelen:

- SlimLaden!-laadpaal
- communicatie met het elektrische voertuig
- aan- en uitschakelen van de stroom naar het elektrische voertuig
- het aanpassen of onderbreken van de laadstroom om veiligheid te garanderen, zoals het voorkomen van overhitting of bij te hoge aardlekstromen.
- status-informatie kan middels
- het tonen van kleuren via een RGB LED (optie)
- Modbus (RS485) status informatie aan andere elektronische systemen beschikbaar stellen
- het vergrendelen van de stekker van de laadkabel (WCD-optie)
- SlimLaden!-meterkast-module

- aansturen van de laadpaal (start/stop/maximale stroom)
- lokale stroom per fase-draad bepalen om overbelasting te vermijden
- informatie-uitwisseling met de gebruiker via een mobiele app
- informatie-uitwisseling met een server op het Internet

SlimLaden! bepaalt zelf het totale energiegebruik van de aansluiting en zal de auto opdracht geven minder snel te laden indien andere apparaten in huis te veel vermogen vragen.

### 4. groepenkast aanpassingen

Uw groepenkast moet de mogelijkheid hebben om het SlimLaden!-laadstation veilig aan te kunnen sluiten. U moet daarvoor ruimte hebben voor een 1-fase of 3-fase aardlekautomaat (30 mA-aardlekschakelaar en de juiste overstroombeveiliging, die afhankelijk is van de maximale stroom voor de laadstations). Indien er geen interne DC-aardlek module EVSE-X-DCD wordt toegepast, dan is een Type-B aardlekschakelaar noodzakelijk. Daarnaast is er ruimte nodig voor de SlimLaden!-meterkast-module (breedte 52 mm). Afhankelijk van de indeling, ruimte en aansluitingen in uw huidige groepenkast kunt u deze onderdelen bijplaatsen of moet de groepenkast worden uitgebreid. Let op: zorg dat er WiFi dekking is in de groepenkast.

U kunt meestal via uw netbeheerder de gegevens van uw huidige aansluiting opvragen. Daarmee kunt u de maximale stroom van uw huisaansluiting controleren. Deze staan ook vaak op de jaarnota van uw energieleverancier.

Wijzigen kan via de website van uw netbeheerder of via https://www.mijnaansluiting.nl/

De netbeheerders in Nederland zijn:

•Enexis: https://www.enexis.nl/

•Liander: https://www.liander.nl/

•Stedin: https://www.stedin.net/

U kunt bij uw netbeheerder meestal informatie opvragen over de richtlijnen van de groepenkast. Wij raden u aan om de aanpassingen in uw groepenkast te laten uitvoeren door een erkende installateur.

In onderstaand schema ziet u hoe de onderdelen in het huis of bedrijfsgebouw en groepenkast globaal aangesloten moet worden.

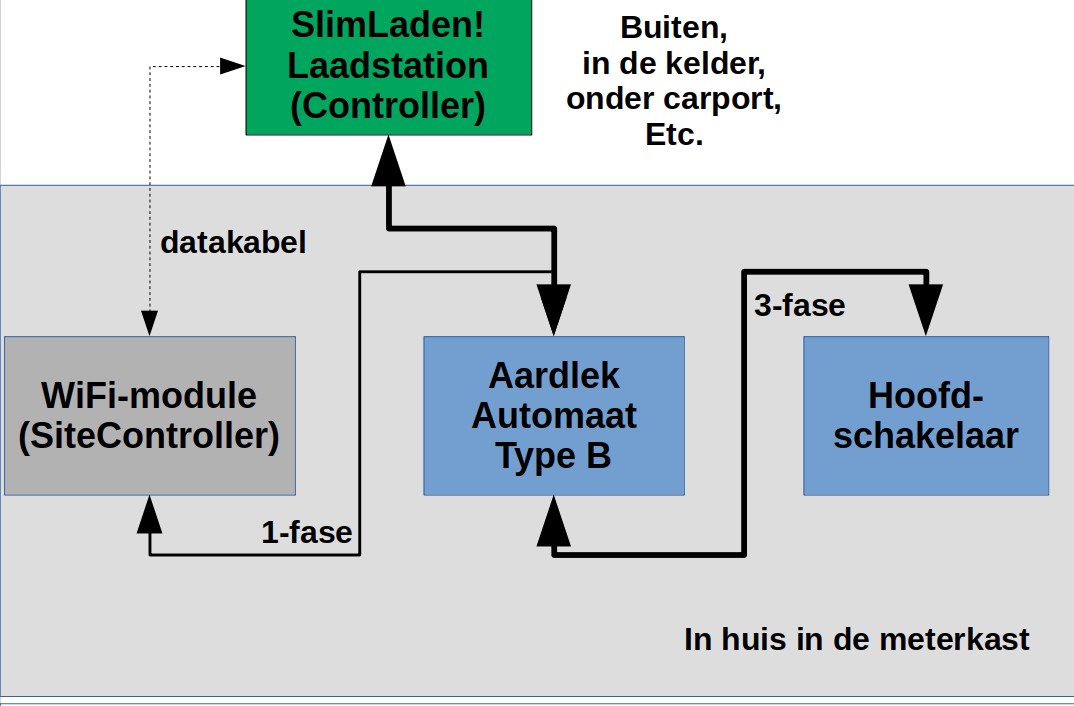
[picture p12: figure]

Van bovenstaand schema ziet u hieronder een voorbeeld van een groepenkast. Deze groepenkast is uitgebreid (bovenste zwarte kast) met de SlimLaden!-meterkast-module (type EVSE-SC-01) en een aardlekautomaat. In deze zwarte kasten zijn de electriciteitsdraden verbonden. Aan de bovenzijde van de bovenste zwarte kast zijn de WiFi-module en en aardlekautomaat met het SlimLaden!-laadstation verbonden (data-kabel en electriciteit).

Indien de SlimLaden!-meterkast-module EVSE-SC-02 wordt gebruikt komt deze buiten de groepenkast en zal via de P1-poort met de slimme meter verbonden worden.
Let op: alleen meters van type DSMR 5.0 of hoger worden ondersteund. Zie https://earn-e.com/slimme-meter/ (https://earn-e.com/slimme-meter/) met een overzicht van de E-nummers van de slimme meters van het juiste type.

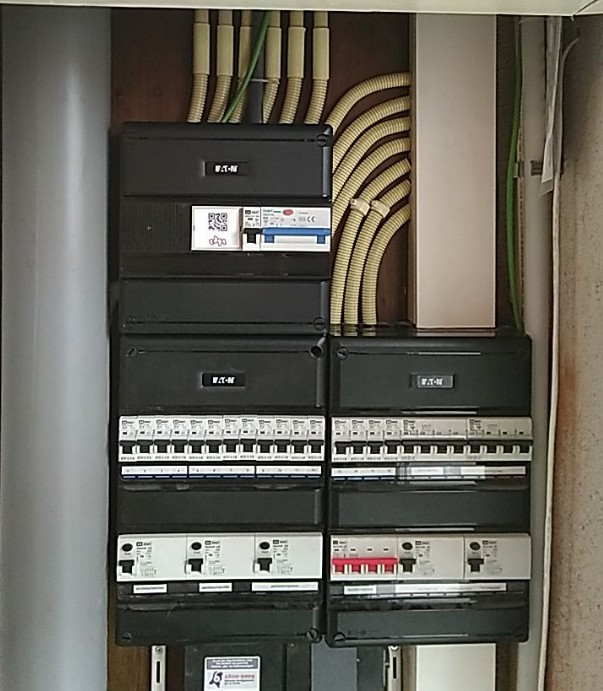
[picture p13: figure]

Hieronder staan de details van de aansluitingen in de groepenkast. Het volgende is belangrijk voor SlimLaden!-meterkast-module EVSE-SC-01:
1. Leg de stroomklemmen om de fase-draden voor de hoofdschakelaar, zodat zeker is dat het totale verbruik van de aansluiting gemeten wordt.
2. Volg de pijl op de stroomklem – die moet de stroomrichting volgens vanaf het netwerk van de netbeheerder naar het huishouden toe
3. Sluit de CT-klemmen correct aan, dus houdt u de nummers en tekens op de WiFi-module goed in de gaten bij het aansluiten.
4. Sluit de De WiFi-module aan op fase-draad L1. Dat is van belang in verband met het bepalen van de fase en stroomrichting op de verschillende draden.

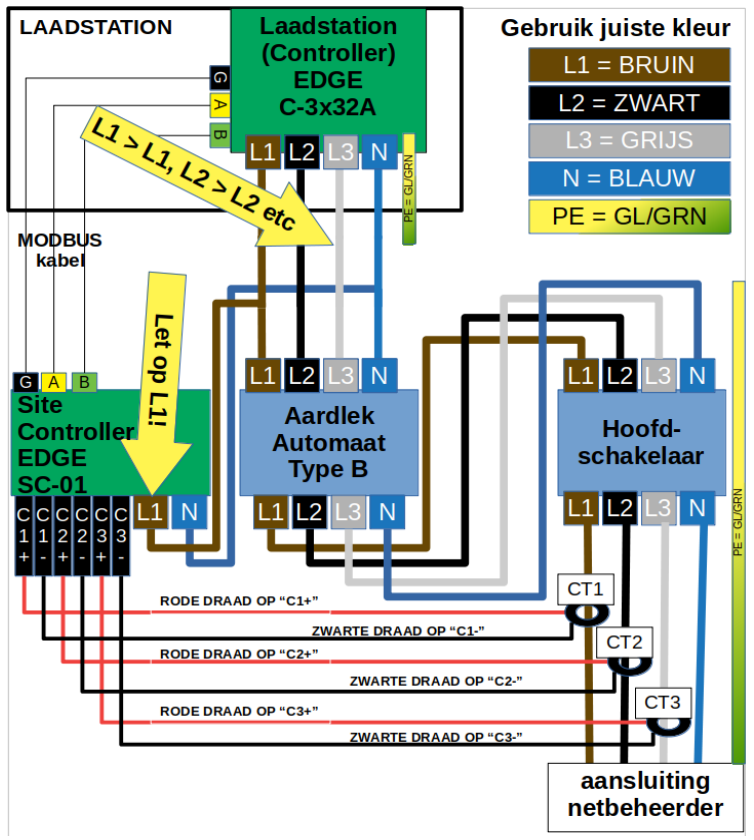
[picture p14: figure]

Verder raden we aan om een gaatje van 5 mm te boren in de afdekplaat van de groepenkast ter hoogte van het LED-lampje, zodat de gebruiker de kleuren en het knipperen van de LED kan zien. Hieronder een voorbeeld hoe dat er uit kan zien, op de foto brandt de LED op de WiFi-module cyaan.

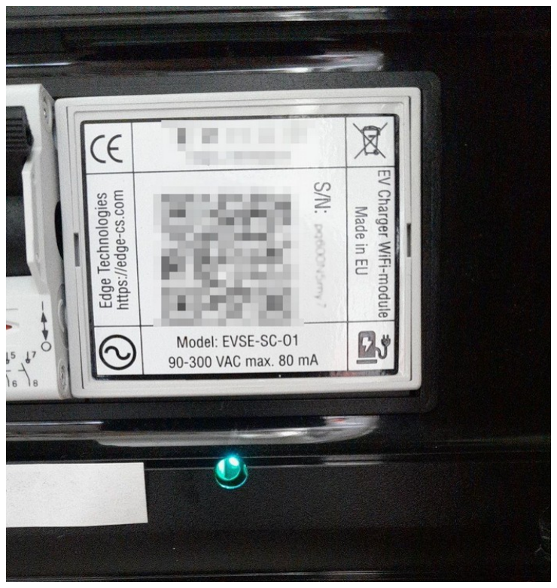
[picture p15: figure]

### 5. Verbinden van het SlimLaden!-laadstation

Op of nabij de plek waar u uw laadpunt wilt hebben moet het SlimLaden!-laadstation worden opgehangen. U dient twee kabels aan te leggen vanaf uw groepenkast naar het SlimLaden!-laadstation:

- laadkabel: de kabel die de electrische stroom naar de auto brengt. Zorg ervoor dat de koperen-aders de juiste dikte hebben voor de grote electrische stroom naar de auto. De benodigde dikte is afhankelijk van het gewenste laadvermogen en de afstand.
- data- of signaalkabel (RS485 Modbus): de kabel die zorgt voor de communicatie tussen de SlimLaden!-meterkast-module en het SlimLaden!-laadstation. Deze moet tenminste 3 aders hebben van minimaal 0,75 mm2 dik. Met deze dikte kunt u afstanden tot 150 meter overbruggen.

Indien de kabels onder de grond lopen dan dient u grondkabel te gebruiken (kabel met een stalen beschermingsmantel en waterdicht) of beide kabels in een mantelbuis te leggen (let dan wel op de juiste diameter omdat er twee kabels doorheen moeten kunnen).

### 5.1. Aansluitingen in het laadstation

Hieronder ziet u de aansluitpunten in het SlimLaden!-laadstation. Let er op dat u de juiste fase-draden gebruikt (L1 op L1, L2 op L2, L3 op L3) en dat de aarde tussen laadkabel, groepenkast en laad-controller correct zijn aangesloten. Het is raadzaam om de fase, neutraal en aarde draden (die vanaf het elektriciteitsnetwerk komen) voldoende de beschermmantel te strippen, zodat deze eenvoudig in de behuizing aan te sluiten zijn. Voor de wantcontactdoos of vaste laadkabel geldt dat deze geleverd wordt met de mantel op de juiste wijze gestript.

De signaalkabel moet op de aansluitpunten aangeduid met “modbus” worden aangesloten:

- “GND”: op de printplaat linkerzijde van de connector, aangeduid met “GND” (“aarde”), sluit deze aan op de “G” op de WiFi-module
- “A/+”: op de printplaat van het laadstation aangeduid “P” van “Positief”
- sluit deze aan op de “B+” op de WiFi-module
- “B/-”: op de printplaat van het laadstation aangeduid “N” van “Negatief”
- sluit deze aan op de “A-” op de WiFi-module

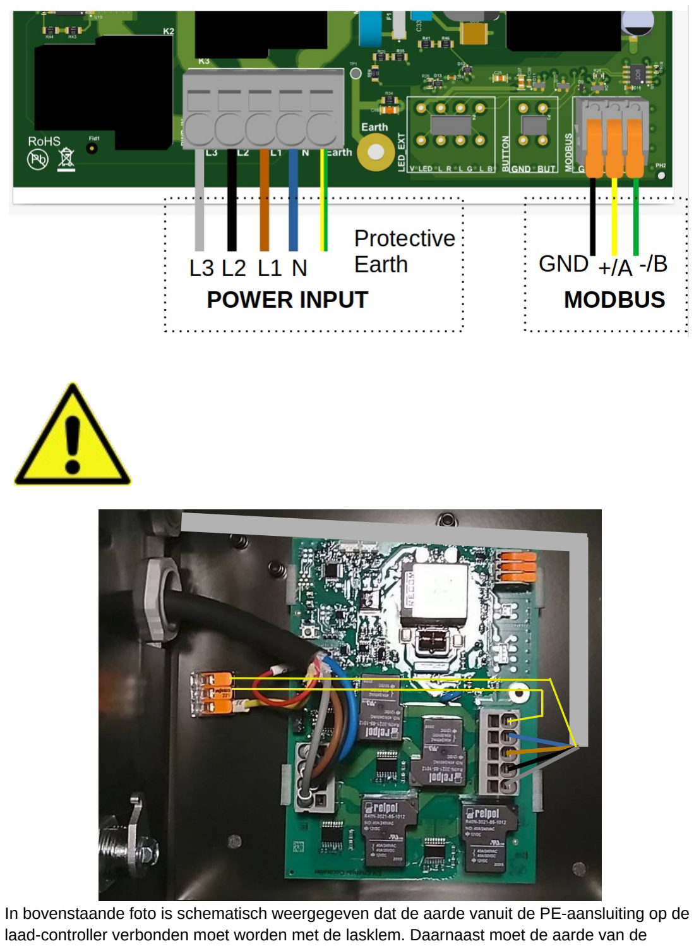
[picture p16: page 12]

In bovenstaande foto is schematisch weergegeven dat de aarde vanuit de PE-aansluiting op de laad-controller verbonden moet worden met de lasklem. Daarnaast moet de aarde van de elektriciteitsaansluiting (schematisch aangeduid als dikke grijze kabel) op diezelfde lasklem worden aangesloten. De aarde van de auto is met gele kabel van de laadkabel op diezelfde lasklem vastgemaakt. Op die wijze is de aarde van de auto verbonden met de aarde van het huis en de aarde van de laad-controller.

Optionele module voor DC-aardlekstromen

Verder is er een optionele module voor het meten van DC-aardlekstromen. We raden de module ten zeerste aan. Deze dient aangesloten te worden op de printplaat van de laad-module middels de meegeleverde kabel (JST-connectoren). Op onderstaande foto ziet u de juiste connector op de printplaat rechts onderin de foto. Haal de uitgaande draden van de laadkabel of de WCD door de ring. Zie ook daarvan een voorbeeld op onderstaande foto. LET OP: haal alle draden (N, L1, L2 en L3) door de ring, behalve de aarde (GND/PE)

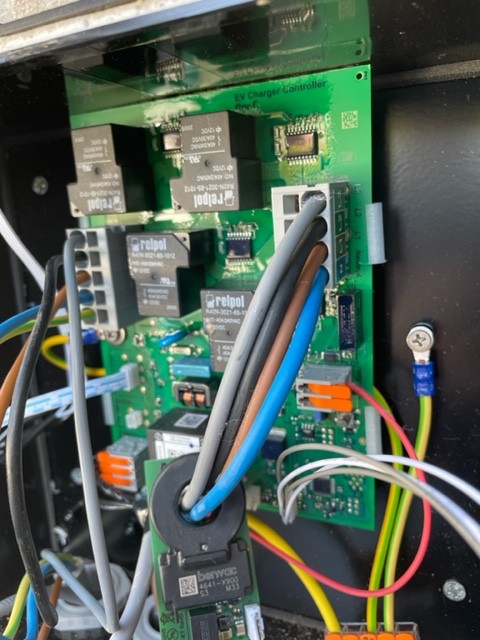
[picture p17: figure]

Extra controle bij gebruik van een WCD

Indien een laadpaal wordt gebruikt met een wantcontactdoos (WCD voor een Mennekes-stekker) is het belangrijk om een extra controle uit te voeren. Voor het bepalen van de maximale toegestane stroom voor een laadkabel dient de zogenaamde proximity pilot (PP) correct aangesloten te zijn.

Het is daarom belangrijk om te controleren dat de PP goed goed contact maakt met de aansluiting op het board (PCB). Onderstaande figuur is een detail van de PCB. De PP-kabel moet zijn aangelosten op de rechter-connector van onderstaande connectoren. Op die connector is een optie om van bovenaf (aangeduid met meetpunt) of zijkant te meten (ingang van de kabel).

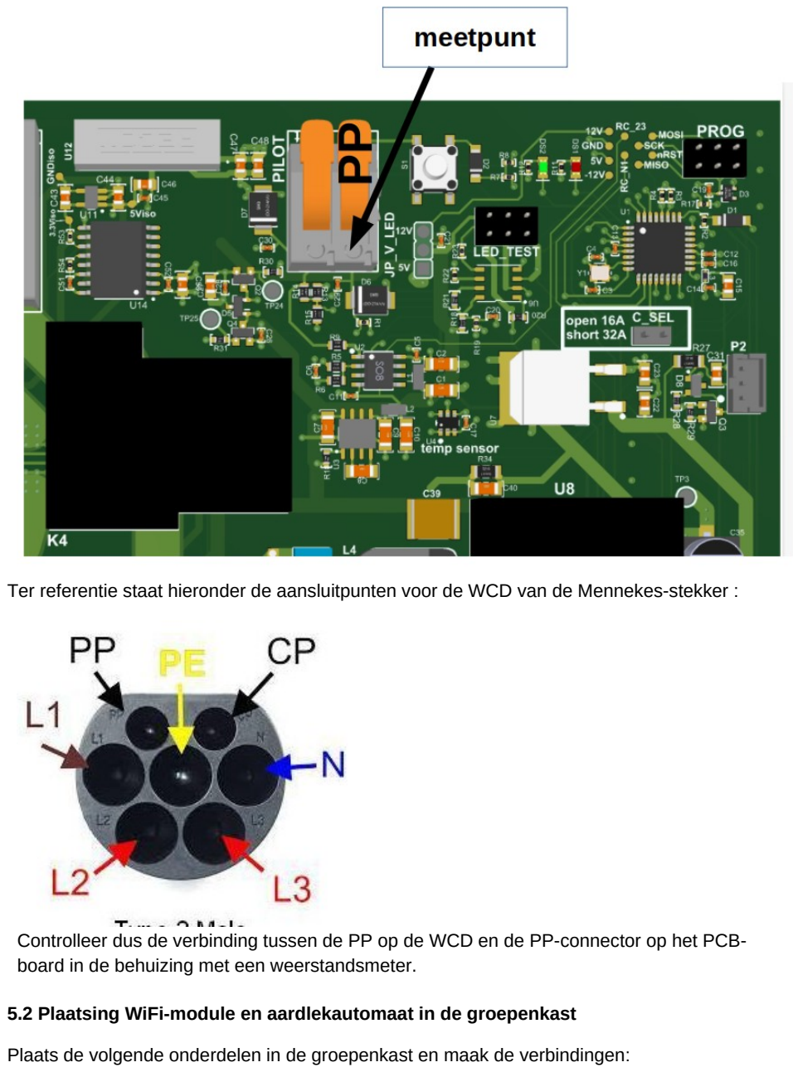
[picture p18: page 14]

Ter referentie staat hieronder de aansluitpunten voor de WCD van de Mennekes-stekker :

Controlleer dus de verbinding tussen de PP op de WCD en de PP-connector op het PCBboard in de behuizing met een weerstandsmeter.

### 5.2 Plaatsing WiFi-module en aardlekautomaat in de groepenkast

Plaats de volgende onderdelen in de groepenkast en maak de verbindingen:

- Aardlekautomaat:
- voedingskabel: deze komt van het laadstation en moet met de aardlekautomaat in de groepenkast verbonden worden.
- WiFi-module:
- Type EVSE-SC-01
- Modbus-aansluiting: verbind de signaalkabel van het laadstation met de WiFi-module. Sluit deze aan op de schroefverbindingen aangeduid met “G”, “A+” en “B-”
- Stroom-aansluiting: de WiFi-module moet ook gevoed worden. Sluit deze aan op schroefverbindingen aangeduid met “N” en “L”
- Stroomklemmen: afhankelijk van de netwerkaansluiting is er 1-fase of zijn er 3 fases. Om de stroom te meten die aan het huis geleverd wordt moet elke fase gemeten worden met een stroomklem. Deze worden meegeleverd. Sluit de stroomklem aan op C1 en klem deze om de eerste fase (L1), C2 klem je om de tweede fase (L2) en C3 klem je om de derde fase (L3). De klemmen moeten worden aangesloten op de stroomdraden van de netbeheerder in de buurt van de hoofdschakelaar direct na de elektriciteitsmeter. Hiervoor kunnen bruine, zwarte of grijze aders gekozen zijn.

LET OP: voor stromen hoger dan 3x35A moeten andere stroomklemmen worden gebruikt. Stromen tot en met 35 Ampère gebruiken stroomklemmen met een wikkelverhouding van 1:1600. Voor stromen boven 35 Ampère moeten stroomklemmen met een wikkelverhouding van 1:2000 worden gebruikt.

- Type EVSE-SC-02
- Modbus-aansluiting: verbind de signaalkabel van het laadstation met de WiFi-module. Sluit deze aan op de “splice”-connector (losse aders niet strippen). Let goed op het verbinden met de juiste kabel, aangeduid met “G”, “A+” en “B-”
- Slimme meter: verbind de module met de P1-poort van de slimme meter en gebruik hiervoor de kabel die aan de behuizing vast zit. Verleng deze kabel niet. Indien er nog andere apparaten aan verbonden zijn moet u gebruik maken van een actieve splitter.
- Voeding: de module wordt gevoed vanuit de P1-poort van de slimme meter
- Netwerk: de module kan met een computer-netwerk verbonden worden via WiFi (WLAN) of een vaste Ethernet-kabel (RJ45 LAN-kabel).

Er lopen twee kabels tussen het SlimLaden!-laadstation en de groepenkast. De voedinsgkabel moet op de aardlekautomaat worden aangesloten, de datakakabel op de WiFi-module, zoals in onderstaand schema staat aangegeven. Hier zijn dezelfde kleuren gebruikt als op de printplaat in het laadstation.

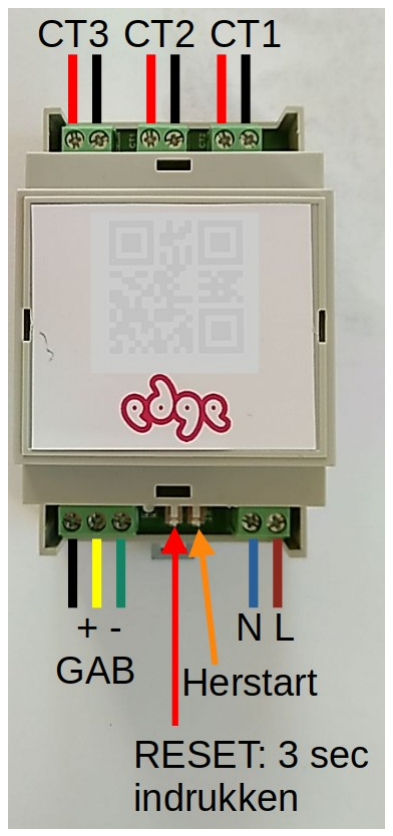
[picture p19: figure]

LET OP! Gebruik de meegeleverde stroomklemmen met de juiste wikkelverhoudingen. Het gebruik van andere stroomklemmen kan tot doorbranden van de module leiden.

Bovenstaande figuur suggereert dat de CT-aansluitngen aan de bovenzijde moeten worden aangesloten. Per situatie kan de handigste oriëntatie worden gekozen. De voeding (N en L1) en Modbus (G, A, B) kunnen soms handiger boven aangesloten worden en CT-aansluitingen juist onderin omdat deze dan misschien dichter bij de hoofdschakelaar zitten en de draden gemakkelijker door de groepenkast heen kunnen worden geleid.

### 5.3. Controle werking

Als de aanpassingen in de groepenkast zijn uitgevoerd en de voedingskabel en datakabel aan beide kanten zijn aangesloten kan de aardlekautomaat worden geactiveerd.

LET OP! De installatie staat nu dus onder stroom dus neem de noodzakelijke veiligheidsmaatregelen die voor het werken met elektrische installaties gelden. Zie de tips voor veiligheid aan het begin van dit document.

Stap 1: Laadstation

U moet nu een elektrisch voertuig of laadpunttester aansluiten. Vervolgens zal de WiFi-module de communicatie met het laadpunt correct opzetten. Zie voor alle details hierover hieronder bij 5.4 waarin het gebruik van de MyCharger-app wordt beschreven.

Het SlimLaden!-laadstation staat standaard ingesteld op “plug & charge” en maximaal 3x16A laden. Als de verbindingen correct zijn gemaakt zal het laadstation de spanning op de uitgaande fase-draden zetten en zal de auto gaan laden of de laadtester zal aangeven dat het laadstation correct is aangesloten.

Binnenin het laadstation: op het board van het laadstation (in de behuizing) bevindt zich een groene en rode LED. Als alleen de groene LED brandt werkt het laadstation. De volgende condities zijn dan mogelijk:

- brandt continue: laadstation is gestart, klaar voor laden
- kort aan, kort uit: laadkabel aangesloten
- kort aan, lang uit: 1 fase laden gestart
- 2x kort aan, lang uit: 3 fase laden gestart

Als de rode LED brandt, dan is er een foto-conditie. Kijk achteraan in dit document om te bepalen wat de fout is.

•Rode LED:

o brandt continue: er is een fout opgetreden

o verschillende volgorde aan/uit: fout-code (expert-functie)

•Groene LED:

o brandt continue: laadstation is gestart, klaar voor laden

o kort aan, kort uit: laadkabel aangesloten

•Blauwe LED:

o brandt continue: laadstation is aan het laden

Als het SlimLaden!-laadstation correct lijkt te werken moet de WiFi-module worden ingesteld.

Stap 2: WiFi-module

Zodra de WiFi-module stroom krijgt via de draden L1 en N, zal deze ingesteld kunnen worden door de MyCharger-app. Voor de zekerheid is het verstandig om de reset-knop tenminste 5 seconden ingedrukt te houden. De module gaat nu naar de toestand om ingesteld te worden, omdat deze knop er voor zorgt dat oude instellingen gewist worden. Het lampje (LED) op de module zal nu blauw knipperen als teken dat deze kan worden ingesteld. In de volgende lijst staan de mogelijke condities van het lampje op de WiFi-module. Dat lampje kan veel verschillende kleuren en patronen weergeven.

Controle-lampje (LED) op de WiFi-module

•Wit: module start op

•Oranje knipperen: fout opgetreden, meestal geen WiFi-verbinding

•Groen: module gestart, netwerk verbonden

•Cyaan: Internet-verbinding

•Blauw: in modus “instellen” (WiFi-gegevens)

### 5.4. Installeer de MyCharger-app

Installeer de MyCharger-app via de Apple Play Store of Android Market.
•Android: https://play.google.com/store/apps/details?id=eu.edgetech.mycharger

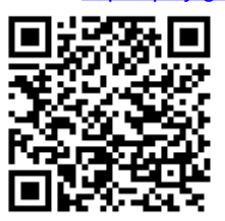
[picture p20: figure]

- IOS: https://apps.apple.com/us/app/mycharger/id1602130655

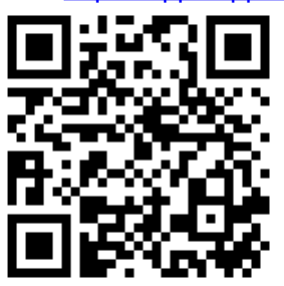
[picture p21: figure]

De volgende belangrijke stappen moeten nu op app worden uitgevoerd: 1 instellen WiFi-gegevens
2 instellen gegevens van de electrische netaansluiting
3 koppelen van het laadstation aan de WiFi-module

4 optioneel gegevens over de auto

1 Instellen WiFi-gegevens
Zodra het lampje op de WiFi-module blauw knippert kan de MyCharger-app gestart worden. De app zal vragen om de WiFi-module te verbinden met het lokale draadloze netwerk. U heeft daarvoor de naam en het wachtwoord van uw lokale draadloze netwerk nodig. Indien u meerdere draadloze netwerken heeft, kies dan het netwerk met het sterkste signaal.

U moet de QR-code fotograferen, maar dat zal verder duidelijk worden in de app. Hieronder een voorbeeld van de WiFi-module geplaatst in de groepenkast met de QR-code.

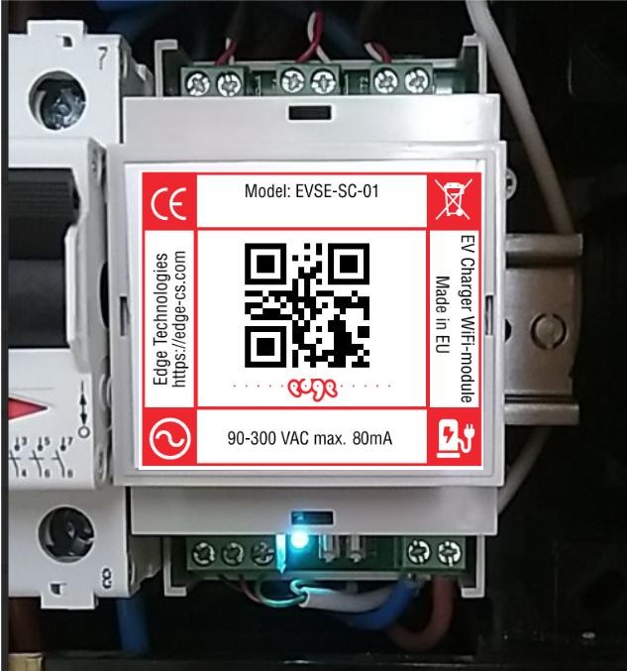
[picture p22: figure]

2 Instellen gegevens van de elektrische aansluiting
Na het instellen van het WiFi-netwerk moet u aangeven welke capaciteit uw elektriciteitsaansluiting heeft. Veel aansluitingen in Nederland hebben een 3-fase aansluiting van 3x25A. Oudere huizen hebben vaak een 1-fase aansluiting van 25A of 40A. Bij twijfel raadpleeg uw installateur, kijk op uw jaarrekening of zoek het op bij uw netbeheerder (zie ook de Internet-linkjes hierboven).

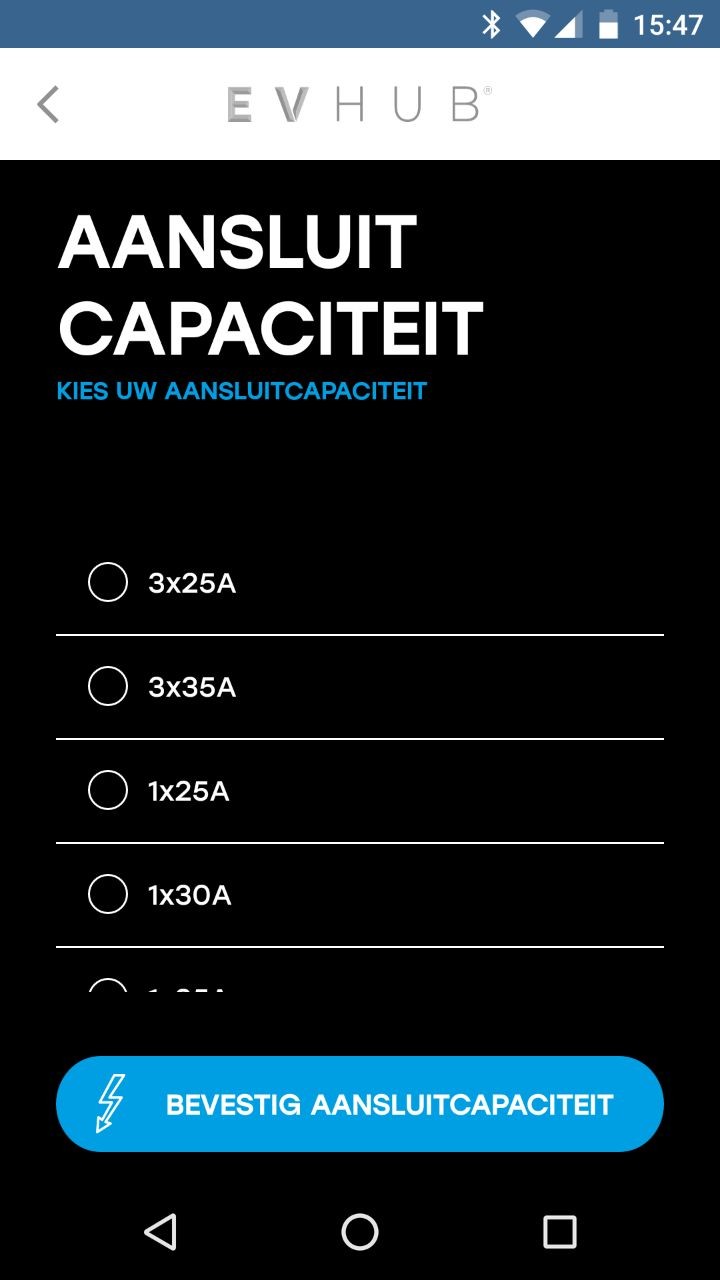
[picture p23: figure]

Let op: het kan zijn dat tijdens het aanmelden van de WiFi-module een nieuwere softwareversie geladen wordt. Het lampje op de WiFi-module knippert dan afwisselend paars/blauw. Als de software geladen is knippert het lampje langzaam met de kleur cyaan. Misschien heeft uw app een foutmelding getoond. Sliuit de app en start deze opnieuw op. U loopt dan opnieuw door stap 1 en 2 heen waarna u verder kunt gaan met stap 3

3 Koppelen van de SlimLaden!-laadpaal
Indien de app nog geen laadpalen kan vinden zal de app doorgaan met de mogelijkheid om een eerste laadpaal te koppelen. Indien de WiFi-module een nieuwe laadpaal gevonden heeft krijgt u de optie om de laadpaal een naam te geven.

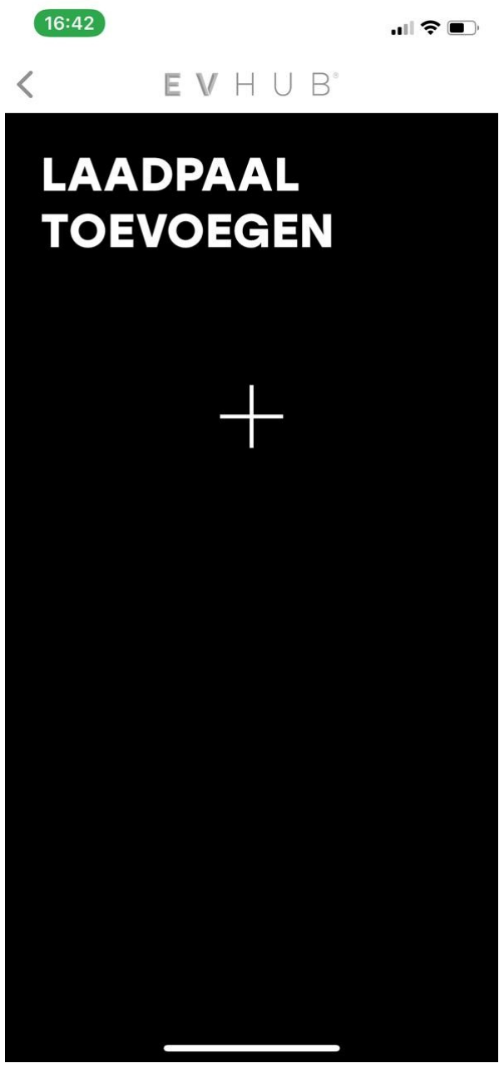
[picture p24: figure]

Indien u nog een laadpaal wilt koppelen kunt u via het instellingsmenu (tandwiel rechtsboven in de app) naar laadpalen toegaan en een laadpaal toevoegen. Dat kan voor de lokale installatie (gekoppeld aan uw eigen WiFi-module) of van een andere installatie waarvoor iemand een code kan sturen om u toegang te verschaffen tot de laadpaal, zie de optie als hieronder in de schermafbeelding is aangegeven.

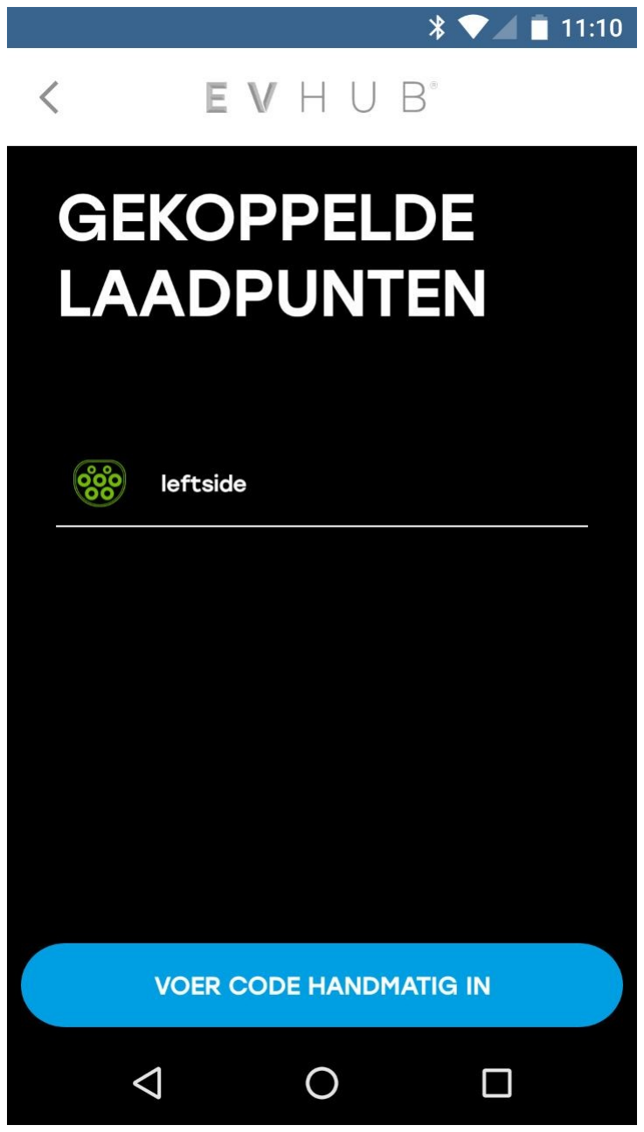
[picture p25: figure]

### 6. Registratie

Wij vragen uw contactgegevens om u te kunnen informeren voor service doeleinden, zoals voor nieuwe functionaliteit, updates en abonnement-gerelateerde zaken. Uw contactgegevens zullen uitsluitend hiervoor gebruikt worden.

U kunt uw contactgegevens bij ons aanmelden via de app.

Op de website https://mycharger.edgetech.nl kunt u uw Slimladen! Abonnement afsluiten of verlengen.

### 7. Abonnement

Met een Slimladen!-abonnement heeft u de beschikking over de volgende diensten:

- verbruiksweergave na elke laadsessie d.m.v. een notificatie
- verbruiksoverzicht in CSV of HTML, te downloaden per zelf gekozen interval via de app
- controle op afstand: start/stop van de gekoppelde laadpunten en uitgesteld laden zodat u de energie consumptie beter kan worden gespreid én u van eventuele avond-/nachttarieven gebruik kunt maken.
- software updates voor de WiFi-module en laadpunt(en). In de toekomst zal de functionaliteit worden verbeterd en/of uitgebreid met bijvoorbeeld voorkeursladen bij gebruik van zonnepanelen en domotica aansluitingen.

Indien u het Slimladen!-abonnement niet verlengd blijft veilig laden (dynamic load-balancing) werken, tenzij de elektriciteitsaansluiting verandert. Bij een aanpassing van de elektriciteitsaansluiting moet de WiFi-module opnieuw worden ingesteld, waarvoor de mobiele app moet worden gebruikt. U moet dan weer een abonnement afsluiten in verband met de communicatie tussen de mobiele app en WiFi-module.

Betalen voor abonnement Slimladen!-meterkast-module (EVSE-SC-01/EVSE-SC-02)

Indien u gebruik wenst te maken van het abonnement kunt u dat via dezelfde link realiseren https://mycharger.edgetech.nl/ met een eenmalige betaling via IDEAL voor 6, 12 of 24 maanden

### 8. Milieu & afvoer

De levensduur is afhankelijk van externe omstandigheden maar naar verwachting onder de juiste condities minimaal 10 jaar. In het geval u oud materiaal wilt afvoeren kunt u het altijd gratis inleveren bij uw leverancier of afvoeren via het afvalbrengstation of een recycle-punt voor elektrisch afval in uw woonplaats.

### 9. Signaal-codes LED

### 9.2 LEDs SlimLaden!-meterkast-module EVSE-SC-02

In zijn algemeenheid geldt dat knipperende groene kleur betekent dat de functie gestart wordt en continue branden dat de functie goed werkt. Indien de LED uit is de functie niet actief.
De volgorde van het starten is: power > network > cloud > activity. De activity-LED zal continue kort knipperen om aan te geven dat er gecommuniceerd wordt met het laadstation. De LED aangeduid met “generic” is voor installateurs en specialisten.
LED | Kleur | Conditie | Omschrijving
Power | Groen | Uit | Geen voeding, niet gestart
| | Knippert | Probeert met slimme meter te verbinden
| | Aan | Voeding OK

Network Groen

| | UIt | Geen computer-netwerk beschikbaar
| | Knippert | Probeert contact te maken met het computer-netwerk
| | Aan | computer-netwerk OK
Cloud (Internet) | Groen | Uit | Geen verbinding met de cloud
| | Knippert | Probeert contact te maken met de cloud
| | Aan | Cloud-verbinding OK
Activity | Groen | Uit | Geen activiteit, geen verbinding met laadstations
| | Knippert | kort aan geeft aan succesvolle communicatie met laadstation(s)
Error | Rood
Uit | Geen fouten

Continue Aan +
Power-LED
uit/knippert

Foute verbinding met de slimme meter (via P1-poort)

Continue Aan +
Network-LED Aan

Fout in laadstation(s)

Knippert | Communicatie-fout met laadstation(s)

### 9.2 Rode LED op de printplaat van de laad-controller (binnenkant kast)

Conditie | Weergave rode LED
Fout bij opstarten (00000001) | Heel lang uit, erg kort aan
Temperatuur hoog (10010000) | Kort aan, kort uit, kort aan, lang uit
Temperatuur te hoog, laden gestopt (10011000) | Kort aan, kort uit, 2x kort aan, lang uit
Geen aarde aangesloten (10011100) | Kort aan, kort uit, 3x kort aan, even uit
Relais blijft ingeschakeld (10011110) | Kort aan, kort uit, 4x kort aan, kort uit
DC-aardlek (10010110) | Kort aan, kort uit, kort aan, kort uit, 2x kort aan, kort uit
Ok | Continue uit

Historie
•17 februari 2020 (versie 0.8)
•9 juni 2020: aanvullingen n.a.v. CE-keuring
•20 augustus 2020: screenshots van de mobiele app toegevoegd •17 september 2020: extra controle bij kast met WCD
•18 november 2020: algemene beschrijvingen toegevoegd
•7 december 2020: plaatjes aangepast
•19 februari 2021: fout-codes toegevoegd
•2 maart 2021: aarde-aansluitingen uitgelegd en notitie over software-upgrade, informatie toegevoegt over registratie en betaling
•25 januari 2022: eisen Modbus-kabel toegevoegd, beter uitleg installatie
•22 februari 2022: aanpassen layout, toevoegen foutcodes
•30 augustus 2022: aanpassen woord meterkast naar groepenkast, toevoegen QR-code instructievideo, correcte verwoording aardlekautomaat en beknopte uitleg
•6 september 2022: toevoegen referentie aderdiktes
•30 november 2022: fout-codes verbeterd
•19 juli 2023: toevoegen gebruik nieuwe SlimLaden!-meterkast-module

De laatste versie vindt u altijd op: https://mycharger.edgetech.nl/Handleiding_SlimLaden.pdf

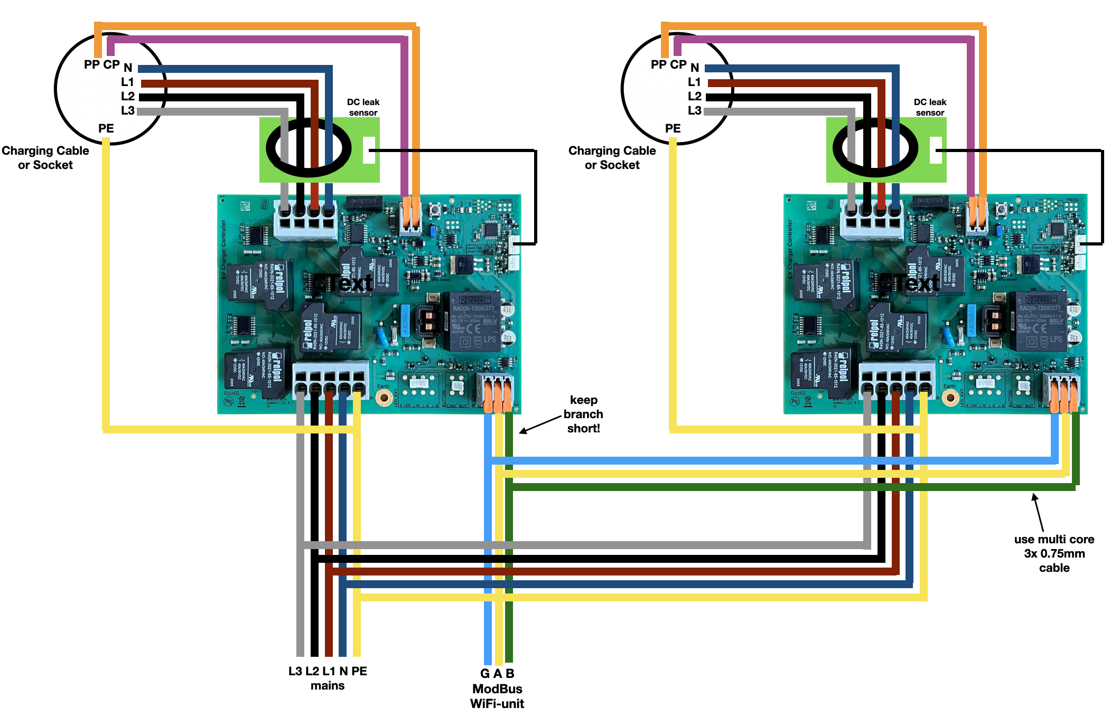
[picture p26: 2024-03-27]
installation/aansluiten-dubbele-laadmodule.png

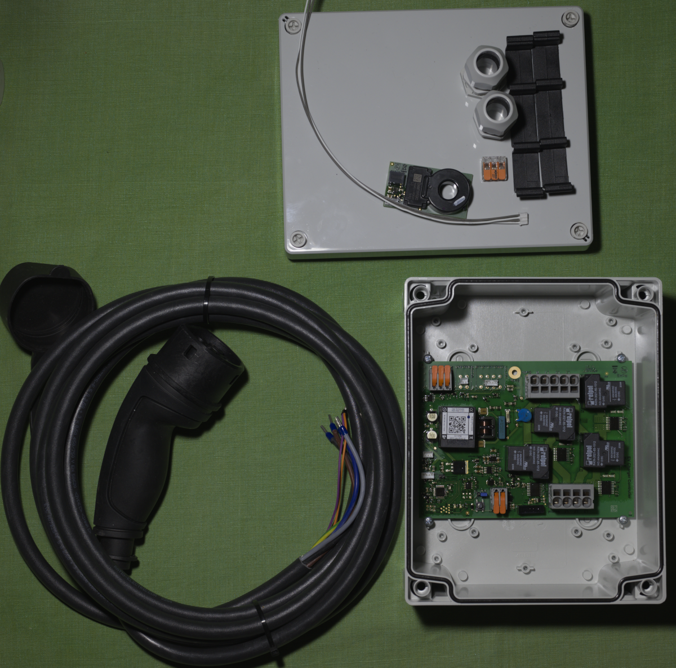
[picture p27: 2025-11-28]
installation/module-kl.png

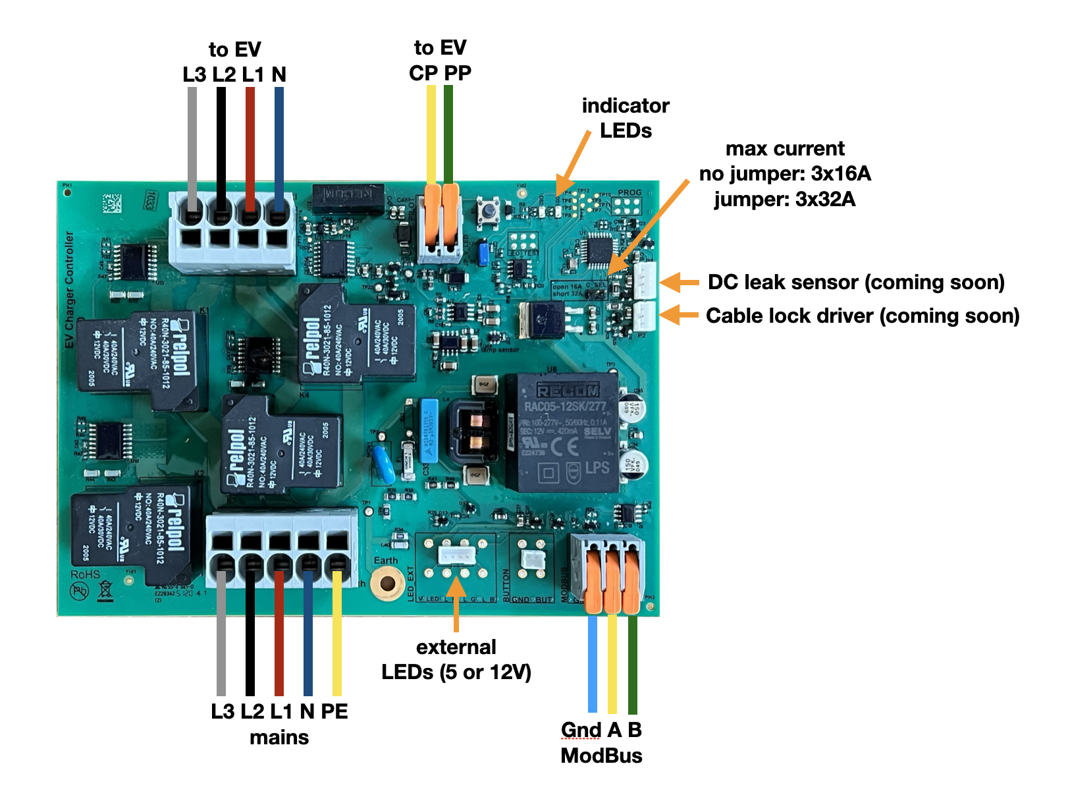
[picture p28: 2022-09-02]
installation/installation.png

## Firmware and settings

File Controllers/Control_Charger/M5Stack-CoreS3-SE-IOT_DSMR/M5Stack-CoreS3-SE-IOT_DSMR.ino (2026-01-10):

/*

  M5Stack M5CoreS3 SE + COMMU

  Board: M5Stack: M5CoreS3

  Connections:
    Charger:              COMMU:   
    ModBud_Ground/white   G (pin 4)
    ModBud_A/yellow       A (pin 2)
    ModBud_B/green        B (pin 1)

  Ext port M5CoreS3:            DSMR:
    Pin 1: SDA/pulse/GPIO1/TX - N.C.
    Pin 2: SCL/edge/GPIO2/RX  - Data, 4K7 resistor to 5V
    Pin 3: 5V                 - N.C.
    Pin 4: GND                - Power ground + Signal ground
                              - Data request tie to 5V

  RJ12 6P6C plug:

             //////
            //////
       +-------------+
      /             /|
     /             / |
    /6 5 4 3 2 1  /  |
   +-+-+-+-+-+-+-+   +
   | | | | | | | |  /
   |             | /
   |   +---+     |/
   +---+   +-----+
       +---+
  
    Pinout:
      1 - +5V
      2 - Data request (tie to +5V for data)
      3 - Data ground
      4 - N.C.
      5 - Data (pull high)
      6 - Power Ground


  Documentation:
  - M5Stack M5CoreS3 SE: https://docs.m5stack.com/en/core/M5CoreS3%20SE
  - COMMU: https://docs.m5stack.com/en/module/commu
  - API: https://docs.m5stack.com/en/arduino/m5unified/m5unified_appendix
  - schematics: https://m5stack-doc.oss-cn-shenzhen.aliyuncs.com/498/Sch_M5_CoreS3_SE_v1.0.pdf
  - schematics COMMU: https://static-cdn.m5stack.com/resource/docs/products/module/commu/commu_sch_01.webp

  Notes:
  - screen size: 320 x 240
  

  Contact us if you help controlling our evse: https://edgetech.eu/

    your friends @ EdgeTech
  
*/
#include <Arduino.h>
#include "SmartEVSE.h"
#include "DSMR5Reader.h"
#include "UI.h"

#define MAX_HOME_CURRENT 25

// the default address of the EdgeTech EVSE has modbus address 1
// be aware that when the address is still 1, the board needs a state change t respond to modbus

#define ADDRESS 1

// room to store the charger state (charge state, currents, voltages)
ChargerState charger_state;

// DSMR smart meter should get new values every second
#define INTERVAL 1000
unsigned long next_time;

// allow for 3x not being able to read values before nulling
#define ALLOW_MISSING 3
unsigned char allow_missing_count;

// the charger has a jumper to hard set the max current to 16a (no jumper) or 32a (jumper)
int board_max_current;

// load balancing
int max_current;
int last_max_current;

// set initial value
#define INITIAL_PHASES 3
int active_phases;

void ui_set_advertizing_current_callback(int advertizing_current) {

  Serial.printf("advertizing %dA\r\n", advertizing_current);

  smart_evse_set_max_current(ADDRESS, advertizing_current, 0);
}

void ui_set_phases_callback(int phases) {

  Serial.printf("set phases to %d\r\n", phases);

  smart_evse_set_phases(ADDRESS, phases==3);
}

void board_init_and_check() {

  bool error;
  int serial[5];
  int version;
  char line[80];

  do {

    error = false;

    ui_clear();

    ui_start_up();

    ui_start_up_add_line("\r\n- Connecting to charger: ");

    smart_evse_init();

    if (!smart_evse_get_serial(ADDRESS, serial)) {

      ui_start_up_add_line_error("not found!\r\n  check wires and address\r\n  change state if at address 1\r\n");
      board_max_current = 0;
      error = true;

    } else {

      ui_start_up_add_line("found!\r\n");
      sprintf(line, "- Serial number: %04x%04x%04x%04x%04x\r\n", serial[0], serial[1], serial[2], serial[3], serial[4]);
      smart_evse_get_fw_version(ADDRESS, &version);
      ui_start_up_add_line(line);
      sprintf(line, "- Firmware version: %d.%d.%d\r\n", version >> 12, (version >> 8) & 0x0f, version & 0xff);
      ui_start_up_add_line(line);
      board_max_current = 16;

      if (smart_evse_is_32_amp(ADDRESS)) {
        board_max_current = 32;
      }

      sprintf(line, "- Board max current: %d\r\n", board_max_current);
      ui_start_up_add_line(line);
    }

    last_max_current = board_max_current;
    max_current = board_max_current;

    dsmr5reader_init();

    int meter_status = dsmr5reader_check();
    if (meter_status != DSMR_OK) {

      sprintf(line, "- No compatible meter found! (code: %d)\r\n", meter_status);
      ui_start_up_add_line_error(line);
      error = true;
    } else {

      sprintf(line, "- DSMR: %s\r\n", dsmr_id);
      ui_start_up_add_line(line);
      if (dsmr_single_phase) {
        sprintf(line, "- Singel phase system\r\n");
      } else {
        sprintf(line, "- Three phase system\r\n");
      }
      ui_start_up_add_line(line);
    }

    ui_start_up_add_line("- Charger comm test: ");
    int errors = 0;
    for (int i = 0; i < 10; i++) {
      bool found_error = false;
      for (int j = 0; j < 10; j++) {
        if (!(smart_evse_get_serial(ADDRESS, serial) && smart_evse_get_fw_version(ADDRESS, &version))) {
          errors++;
          found_error = true;
        }
      }
      if (found_error) {
        ui_start_up_add_line_error("x");
      } else {
        ui_start_up_add_line(".");
      }
    }
    int quality = 100 - errors;
    sprintf(line, " %d%%\r\n", quality);
    if (quality < 100) {
      ui_start_up_add_line_error(line);
      error = true;
    } else {
      ui_start_up_add_line(line);
    }

    if (error) {

      ui_start_up_add_line_error("\r\nErrors: restarting...");

      ui_delay_untill_tapped(5000);
    }

  } while (error);

  ui_start_up_add_line("\r\nAll fine!");
}

void setup(void) {

  ui_init();
  ui_splash();

  Serial.begin(115200);

  Serial.printf("\r\n\r\nM5Stack CoreS3 SE\r\n\r\n");

  ui_delay_untill_tapped(5000);

  board_init_and_check();

  ui_delay_untill_tapped(30000);

  ui_clear();

  // make sure the charge is in sync
  active_phases = INITIAL_PHASES;
  ui_set_advertizing_current_callback(max_current);
  ui_set_phases_callback(active_phases);
  allow_missing_count = ALLOW_MISSING;

  ui_setup_main(board_max_current, active_phases);

  next_time = millis() + INTERVAL;
}


void loop(void) {

  unsigned long now = millis();

  if (dsmr5reader_process_line()) {

    // Serial.printf("Current: %f, %f, %f\r\n", dsmr_current[0], dsmr_current[1], dsmr_current[2]);

    ui_set_home_values(dsmr_current);
  }

  if (now > next_time) {

    next_time = now + INTERVAL;

    ui_start_update();

    smart_evse_get_charger_state(ADDRESS, &charger_state);

    // calculate advertizing current
    max_current = board_max_current;
    for (int i = 0; i < 3; i++) {
      int spare = MAX_HOME_CURRENT - dsmr_current[i] + charger_state.c[i];
      if (spare < max_current) {
        max_current = spare;
      }
    }
    if (max_current < 6) {
      max_current = 0;
    }

    if (last_max_current != max_current) {

      last_max_current = max_current;

      ui_set_advertized(max_current);

      ui_set_advertizing_current_callback(max_current);
    }

    if (charger_state.isNew) {

      allow_missing_count = ALLOW_MISSING;

      charger_state.isNew = false;

      // Serial.printf("state: %d, error: %d, temperature: %d, cable: %d a\r\n",
      //                charger_state.state, charger_state.error, charger_state.temperature, charger_state.cable_current);
      // Serial.printf("current: %f, %f, %f a\r\n", charger_state.c[0], charger_state.c[1], charger_state.c[2]);
      // Serial.printf("voltage: %f, %f, %f v\r\n", charger_state.v[0], charger_state.v[1], charger_state.v[2]);
      // Serial.printf("session: %f kwh, total: %f kwh\r\n\r\n", charger_state.kwh_session, charger_state.kwh_total);

      ui_set_ev_values(charger_state);

    } else {

      if (allow_missing_count) {
        allow_missing_count--;
        if (!allow_missing_count) {
          ui_unset_ev_values();
        }
      }
    }

    ui_end_update();
  }

  ui_process();
}

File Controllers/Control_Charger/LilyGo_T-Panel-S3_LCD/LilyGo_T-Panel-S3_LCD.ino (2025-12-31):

/*

  LillyGo T-Panel S3 RS485

  Board: esp32: ESP32S3 Dev Module
  - USB CDC On Boot	  Enabled
  - Flash Size	      16MB (128Mb)
  - Partition Scheme	16M Flash (3MB APP/9.9MB FATFS)
  - PSRAM	            QSPI PSRAM

  Connections:
    Charger:              T-Panel:   
    ModBud_Ground/white   SGND
    ModBud_A/yellow       L
    ModBud_B/green        H

  Documentation:
  - https://lilygo.cc/products/t-panel-s3?srsltid=AfmBOoqK3WmcNyMwsreH9n6bwDtGik-VFqjp-NglJnTqaYiQIHH78q6t
  - https://github.com/Xinyuan-LilyGO/T-Panel
  - https://github.com/Xinyuan-LilyGO/T-Panel/blob/arduino-esp32-libs_V2.0.14/project/T-Panel_V1.2.pdf

  Note:
  - for lvgl to work it needs esp32 bsp 2.x (3.x does not compile)
  - also install the libraries in the "libraries" folder of this sketch

  Contact us if you help controlling our evse: https://edgetech.eu/

    your friends @ EdgeTech

*/

#define TOUCH_MODULES_CST_MUTUAL


#include "lvgl.h"
#include "misc/lv_color.h"
#include "Arduino_GFX_Library.h"
#include "pin_config.h"
#include "TouchLib.h"
#include "SmartEVSE.h"
#include "UI.h"

// the default address of the EdgeTech EVSE has modbus address 1
// be aware that when the address is still 1, the board needs a state change t respond to modbus

#define ADDRESS 1


unsigned long next_time;

ChargerState charger_state;


volatile bool Touch_Int_Flag = false;

TouchLib touch(Wire, TOUCH_SDA, TOUCH_SCL, CST3240_ADDRESS);

Arduino_DataBus *bus = new Arduino_XL9535SWSPI(IIC_SDA /* SDA */, IIC_SCL /* SCL */, -1 /* XL PWD */,
                                               XL95X5_CS /* XL CS */, XL95X5_SCLK /* XL SCK */, XL95X5_MOSI /* XL MOSI */);

Arduino_ESP32RGBPanel *rgbpanel = new Arduino_ESP32RGBPanel(
  -1 /* DE */, LCD_VSYNC /* VSYNC */, LCD_HSYNC /* HSYNC */, LCD_PCLK /* PCLK */,
  LCD_B0 /* B0 */, LCD_B1 /* B1 */, LCD_B2 /* B2 */, LCD_B3 /* B3 */, LCD_B4 /* B4 */,
  LCD_G0 /* G0 */, LCD_G1 /* G1 */, LCD_G2 /* G2 */, LCD_G3 /* G3 */, LCD_G4 /* G4 */, LCD_G5 /* G5 */,
  LCD_R0 /* R0 */, LCD_R1 /* R1 */, LCD_R2 /* R2 */, LCD_R3 /* R3 */, LCD_R4 /* R4 */,
  1 /* hsync_polarity */, 20 /* hsync_front_porch */, 2 /* hsync_pulse_width */, 0 /* hsync_back_porch */,
  1 /* vsync_polarity */, 30 /* vsync_front_porch */, 8 /* vsync_pulse_width */, 1 /* vsync_back_porch */,
  10 /* pclk_active_neg */, 6000000L /* prefer_speed */, false /* useBigEndian */,
  0 /* de_idle_high*/, 0 /* pclk_idle_high */);

Arduino_RGB_Display *gfx = new Arduino_RGB_Display(
  LCD_WIDTH /* width */, LCD_HEIGHT /* height */, rgbpanel, 0 /* rotation */, true /* auto_flush */,
  bus, -1 /* RST */, st7701_type9_init_operations, sizeof(st7701_type9_init_operations));

static lv_disp_draw_buf_t draw_buf;
static lv_disp_drv_t disp_drv;

/* Display flushing */
void my_disp_flush(lv_disp_drv_t *disp, const lv_area_t *area, lv_color_t *color_p) {

  uint32_t w = (area->x2 - area->x1 + 1);
  uint32_t h = (area->y2 - area->y1 + 1);

  gfx->draw16bitRGBBitmap(area->x1, area->y1, (uint16_t *)&color_p->full, w, h);

  lv_disp_flush_ready(disp);
}

/*Read the touchpad*/
void my_touchpad_read(lv_indev_drv_t *indev_drv, lv_indev_data_t *data) {

  if (Touch_Int_Flag == true) {

    touch.read();
    TP_Point t = touch.getPoint(0);

    if ((touch.getPointNum() == 1) && (t.pressure > 0) && (t.state != 0)) {

      data->state = LV_INDEV_STATE_PR;

      /*Set the coordinates*/
      data->point.x = t.x;
      data->point.y = t.y;

      // Serial.printf("Touch X: %d Y: %d", t.x, t.y);
      // Serial.printf("Static: %d", t.state);
      // Serial.printf("Pressure: %d", t.pressure);
    }

    Touch_Int_Flag = false;

  } else {

    data->state = LV_INDEV_STATE_REL;
  }
}

void lvgl_initialization(void) {

  lv_init();

  uint32_t screen_width = gfx->width();
  uint32_t screen_height = gfx->height();

  lv_color_t *buf_1 = (lv_color_t *)heap_caps_malloc(sizeof(lv_color_t) * LCD_WIDTH * 40, MALLOC_CAP_INTERNAL | MALLOC_CAP_8BIT);
  lv_color_t *buf_2 = (lv_color_t *)heap_caps_malloc(sizeof(lv_color_t) * LCD_WIDTH * 40, MALLOC_CAP_INTERNAL | MALLOC_CAP_8BIT);

  while ((!buf_1) || (!buf_2)) {

    Serial.println("LVGL disp_draw_buf allocate failed!");
    delay(1000);
  }

  lv_disp_draw_buf_init(&draw_buf, buf_1, buf_2, LCD_WIDTH * 40);

  /* Initialize the display */
  lv_disp_drv_init(&disp_drv);
  /* Change the following line to your display resolution */
  disp_drv.hor_res = screen_width;
  disp_drv.ver_res = screen_height;
  disp_drv.flush_cb = my_disp_flush;
  disp_drv.draw_buf = &draw_buf;
  disp_drv.full_refresh = 1;
  lv_disp_drv_register(&disp_drv);

  /*Initialize the (dummy) input device driver*/
  static lv_indev_drv_t indev_drv;
  lv_indev_drv_init(&indev_drv);
  indev_drv.type = LV_INDEV_TYPE_POINTER;
  indev_drv.read_cb = my_touchpad_read;
  lv_indev_drv_register(&indev_drv);
}

void ui_set_advertizing_current_callback(int advertizing_current) {

    Serial.printf("advertizing %dA\r\n", advertizing_current);
}

void ui_set_phases_callback(int phases) {

    Serial.printf("set phases to %d\r\n", phases);
}

void setup() {

  Serial.begin(115200);

  Serial.printf("\r\nLiliGo  T-Panel LVGL\r\n\r\n");

  pinMode(LCD_BL, OUTPUT);
  digitalWrite(LCD_BL, HIGH);

  attachInterrupt(
    TOUCH_INT,
    [] {
      Touch_Int_Flag = true;
    },
    FALLING);

  Wire.begin(IIC_SDA, IIC_SCL);

  gfx->begin();
  gfx->fillScreen(BLACK);

  gfx->XL_digitalWrite(XL95X5_TOUCH_RST, LOW);
  delay(200);
  gfx->XL_digitalWrite(XL95X5_TOUCH_RST, HIGH);
  delay(200);

  touch.init();

  lvgl_initialization();

  smart_evse_init();
  charger_state.count = 0;
  charger_state.error_count = 0;


  int board_max_current = 16;

  if (smart_evse_is_32_amp(ADDRESS)) {
    board_max_current = 32;
  }

  ui_init(board_max_current);

  Serial.printf("init done\r\n");

  Serial.printf("Request serial and fw version:\r\n");



  smart_evse_get_serial(ADDRESS);

  smart_evse_get_fw_version(ADDRESS);

  smart_evse_get_max_currents(ADDRESS);

  next_time = millis() + 1000;
}



void loop() {

  unsigned long now = millis();

  lv_timer_handler();
  delay(5);

  if (now > next_time) {

    next_time = now + 1000;

    smart_evse_get_charger_state(ADDRESS, &charger_state);

    if (charger_state.isNew) {

      charger_state.isNew = false;

      Serial.printf("state: %d, error: %d, temperature: %d, cable: %d a\r\n",
                    charger_state.state, charger_state.error, charger_state.temperature, charger_state.cable_current);
      Serial.printf("current: %f, %f, %f a\r\n", charger_state.c[0], charger_state.c[1], charger_state.c[2]);
      Serial.printf("voltage: %f, %f, %f v\r\n", charger_state.v[0], charger_state.v[1], charger_state.v[2]);
      Serial.printf("session: %f kwh, total: %f kwh\r\n\r\n",charger_state.kwh_session, charger_state.kwh_total);

      ui_set_ev_values(charger_state);
    }
  }
}

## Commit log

2022-09-05 initial checkin
    [bracket c-thickness parameterized v3.3mf, bracket c-thickness parameterized v3.f3d, bracket c-thickness parameterized v3.stl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]
2024-03-27 reorganized documentation
    [bracket.step]
2024-10-28 Create adding LED to charger.pdf
2025-11-19 diy controllers for charger
    diy controllers for charger
2025-11-28 Create DHZ laadpaal assembly guide
    Added a guide for assembling the DHZ laadpaal with safety instructions.
2025-11-28 Fix formatting and enhance assembly instructions
    Corrected formatting and added detailed assembly instructions for the DHZ laadpaal.
2025-11-28 LEDs op het bord
2025-11-28 Revise safety guidelines and enhance assembly visuals
    Updated safety section to emphasize importance of professional installation and added images for clarity in assembly instructions.
2025-11-28 Add LED connection instructions to DHZ-laadpaal.md
    Added instructions for connecting an LED to the charging module.
2025-11-28 Fix link formatting for LED connection in documentation
    Corrected link formatting for LED connection instructions.
2025-11-28 Fix LED connection link in DHZ-laadpaal.md
    Updated link to LED connection diagram with proper URL encoding.
2025-12-04 fritzing connection diagram
    fritzing connection diagram
    [ConnectionDiagram_DSMR5_Pico2W.fzz]
2025-12-08 pico 2w modbus
2025-12-08 human readable states & errors
    human readable states & errors
    [Raspberry_Pico2W_2CH_RS485.ino]
2025-12-09 Update DHZ-laadpaal.md with assembly instructions
    Added information about assembling the housing and using mounting brackets.
2025-12-09 Update image reference in assembly steps
2025-12-09 Update assembly instructions with Modbus cable advice
    Added recommendation for Modbus cable alongside power cable in assembly steps.
2025-12-09 Update grounding wire instructions in DHZ-laadpaal.md
    Clarify connection instructions for grounding wire in the WAGO connector.
2025-12-09 Clarify connection instructions for WAGO-connector
    Replaced 'meegeleverde draad aardedraad' with 'meegeleverde losse WAGO-connector' for clarity in instructions.
2025-12-09 Update DHZ-laadpaal.md with LED check instructions
    Added important note about checking ground connection if the red LED blinks.
2025-12-09 Enhance DHZ-laadpaal.md with testing and load-balancing
    Added a section for testing car charging and load-balancing.
2025-12-09 Enhance troubleshooting section with LED error table
    Added a table for LED error conditions during car charging.
2025-12-09 Update error conditions and LED indicators in documentation
    Added additional error conditions and LED indicators for the charging module.
2025-12-09 Fix duplicate line in DHZ-laadpaal.md
    Removed duplicate line about Raspberry Pi model 3B.
2025-12-09 Add DIY charging station guide
    This document provides a step-by-step guide for building a DIY charging station, including configurations for load balancing and smart meter connections.
2025-12-09 Clarify basic configuration and add assembly steps
    Updated the basic configuration section to clarify that the charging point does not take other power users into account, and added detailed assembly steps for connecting the charging module and testi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
2025-12-09 Fix formatting and indentation in DIY-chargepoint.md
2025-12-09 Remove extra line before LED warning
    Removed redundant line before the important note about the red LED.
2025-12-09 Fix formatting of LED display conditions table
    Formatted the table for red LED display conditions in the charging module section.
2025-12-09 Fix formatting in charging fault LED display
    Updated the red LED display conditions for charging faults.
2025-12-09 Add load balancing section to DIY chargepoint guide
    Added a section on load balancing for charging points, detailing options for experienced hobbyists and Linux users, including hardware recommendations and configuration steps.
2025-12-09 Revise assembly instructions and image paths
    Updated the assembly instructions and image references for the DIY charge point.
2025-12-10 board.h
    board.h
2025-12-15 Add Dutch link to DIY charging station document
2025-12-15 Fix link formatting in DIY-chargepoint.md
2026-01-02 1/3 phase button
    1/3 phase button
